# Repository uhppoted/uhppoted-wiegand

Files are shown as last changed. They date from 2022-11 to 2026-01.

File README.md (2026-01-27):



# uhppoted-wiegand

`uhppoted-wiegand` implements a RaspberryPi RP2040 based reader/emulator for a Wiegand-26 interface for:
- development, testing and debugging of access control software
- interfacing non-standard and off-brand readers and keypads to the UHPPOTE L0x access controllers

The project includes:
- _M5Stack_ Wiegand-26 emulator with:
   - isolated interface capable driving up to 32mA loads
   - can be powered from M5 bus, USB or external 12VDC supply
   - emulates both card reader and 4-bit/8-bit keypad modes
   - can operate either standalone or as an _M5Stack_ module

- breadboard prototypes
   - PIO based Wiegand-26 reader emulator which can write a Wiegand-26 card out to a controller
   - PIO based Wiegand-26 controller emulator which can read from Wiegand-26 reader and unlock a door
   - PIO based Wiegand-26 'universal' reader/writer implementation

## Status

### M5Stack

1. Wiegand emulator (Rev. 0)

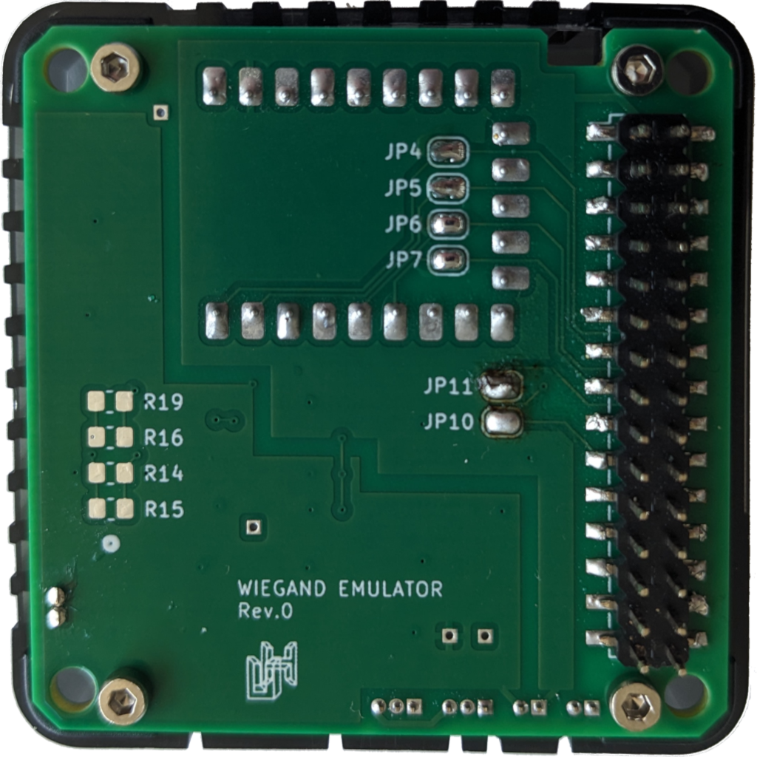
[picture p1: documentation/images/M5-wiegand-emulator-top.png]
|||

Includes:
- KiCad schematic and PCB layout
- Firmware for _Waveshare Tiny RP2040_
- Example Micropython application for _M5Stack_ _CoreS3_.

#### Errata
1. Pads for SK6812 are incorrectly numbered.
2. Anode and cathode swapped pads for D2, D3 and D4 are swapped.
3. ISO7841 doesn't allow RC filter on LED input.
4. Insufficient clearance around mounting holes.
5. DI and DO are pulled low on power-up (should default to _high_).
6. Solder mask does not include M5 connectors.
7. GPIO pins are incorrect (IO1 and IO2 instead of IO6 and IO7).

### Prototype

Breadboarded and Fritzing'ed implementations of:
- Wiegand-26 reader emulator
- Wiegand-26 controller emulator
- Wiegand-26 'universal' reader/writer

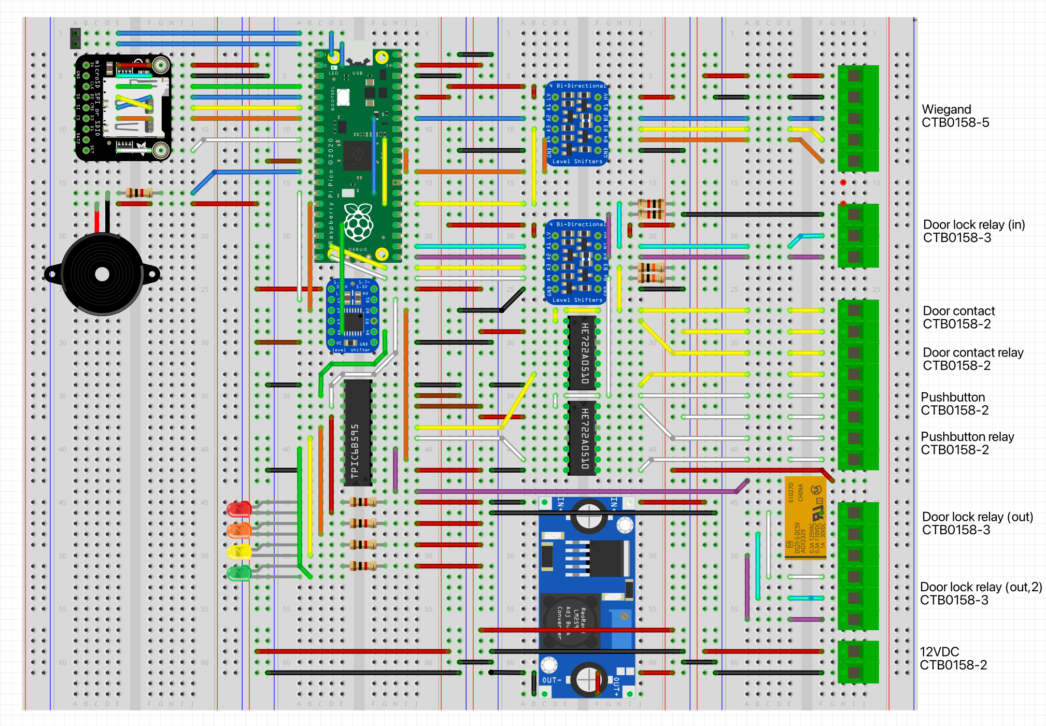
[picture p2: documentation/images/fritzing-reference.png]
 

## Release Notes

### Current Release

**[v0.9.0](https://github.com/uhppoted/uhppoted-wiegand/releases/tag/v0.9.0) - 2026-01-27**
1. Fixed GPIO card constants.
2. Added second page with keypad to demo application.

**[v0.8.11](https://github.com/uhppoted/uhppoted-wiegand/releases/tag/v0.8.11) - 2025-07-30**

1. Added M5 stack Wiegand emulator Rev.0.

## Breadboard

### Building from source

Required tools:
- [Raspberry Pi Pico C/C++ SDK](https://datasheets.raspberrypi.com/pico/raspberry-pi-pico-c-sdk.pdf)
- Compatible C/C++ compiler
- _make_
- [PicoProbe](https://github.com/raspberrypi/picoprobe) (optional but recommended)
- [OpenOCD](https://github.com/raspberrypi/openocd.git) (optional but recommended)
- [PicoTool](https://github.com/raspberrypi/picotool) (optional but recommended)

To build using the included _Makefile_:
```
git clone https://github.com/uhppoted/uhppoted-wiegand.git
cd uhppoted-wiegand/breadboard/pico
make clean
make build
```

The `build` target produces both a UF2 and an ELF binary for installation on a _Raspberry Pi Pico_ using either:
- USB (using _BOOTSEL_)
- _PicoProbe_ + _OpenOCD_
- _PicoTool_

- The `make install` command installs the binary using _PicoTool_
- The `make run` command installs the binary using _PicoProbe_ and _OpenOCD_

### Usage

The provided software includes a **very** bare bones serial port command interface. Commands are (currently)
single letter mnemonics and need to be terminated by a carriage return and/or line feed.

The supported command set comprises:

| *Command* | *Mode* | *Description* |
| ---|---|---|
| TIME yyyy-mm-dd HH:mm:ss | _ALL_ | Set date/time |
| CARD nnnnnnnn | _emulator_ | Emulates card swipe |
| CODE dddddd | _emulator_ | Emulates keypad |
| | | |
| LIST ACL | _controller_ | List cards in ACL |
| CLEAR ACL | _controller_ | Deletes all cards in ACL |
| GRANT nnnnnn dddddd | _controller_ | Grant card (+ optional PIN) access rights |
| REVOKE nnnnnn | _controller_ | Revoke card access rights |
| QUERY | _controller_ | Display last card read/write |
| | | |
| MOUNT | _ALL_ | Mount SD card |
| UNMOUNT | _ALL_ | Unmount SD card |
| FORMAT | _ALL_ | Format SD card |
| | | |
| UNLOCK | _controller_ | Unlocks door for 5 seconds |
| | | |
| OPEN | _emulator_ | Emulates door open contact |
| CLOSE | _emulator_ | Emulates door close contact |
| PRESS | _emulator_ | Emulates pushbutton press |
| RELEASE | _emulator_ | Emulates pushbutton release |
| | | |
| BLINK | _ALL_ | Blinks reader LED 5 times |
| CLS | _ALL_ | Reinitialises terminal |
| REBOOT | _ALL_ | Reboot |
| ? | _ALL_ | Display list of commands |

### Operating Modes

The codebase currently supports two operating modes:
- emulator
- controller

In _emulator_ mode the implementation writes a Wiegand-26 card code (or keypad PIN code) to an external Wiegand-26 interface
(e.g. a UHPPOTE controller). It also:
- emulates a door open/closed sensor
- emulates a door pushbutton
- detects the door locked/unlocked state

In _controller_ mode the implementation reads a Wiegand-26 card code (or keypad PIN code) from an external Wiegand-26 reader/keypad. It also:
- detects a door open/closed sensor state change
- detects a door pushbutton state change
- emulates a door lock/unlock
- implements card permissions and keypad passcodes

The operating mode is set by the combination of the code and the JUMPER_READ and JUMPER_WRITE inputs (set in _hwconfig.c_, 
GPIO7 and GPIO8 by default):
- the _controller_ binaries expect the JUMPER_READ input to be pulled LOW
- the _emulator_ binaries expected the JUMPER_WRITE input to be pulled LOW
- the _universal_ binaries start in _reader_ mode if the JUMPER_READ input is pulled LOW, or in _writer_ mode if the 
  JUMPER_WRITE is pulled LOW
- if both JUMPER_READ and JUMPER_WRITE are pulled LOW the operating mode is UNKNOWN.

### Keypad emulation

The code supports two keypad modes:
- 4-bit burst mode
- 8-bit burst mode

In 4 bit burst mode, each keypress is sent as 4 bit code followed by a 28-bit 'space', with keypad digits encoded as follows:

| Digit | 0 | 1 | 2 | 3 | 4 | 5 | 6 | 7 | 8 | 9 | * | # |
|---|---|---|---|---|---|---|---|---|---|---|---|---|
| Code  | 0000 | 0001 | 0010 | 0011 | 0100 | 0101 | 0110 | 0111 | 1000 | 1001 | 1010 | 1011 |

In 8 bit burst mode, each keypress is sent as 8 bit code followed by a 24-bit 'space', with keypad digits encoded as follows:

| Digit | 0 | 1 | 2 | 3 | 4 | 5 | 6 | 7 | 8 | 9 | * | # |
|---|---|---|---|---|---|---|---|---|---|---|---|---|
| Code  | 11110000 | 11100001 | 11010010 | 11000011 | 10110100 | 10100101 | 10010110 | 10000111 | 01111000 | 01101001 | 01011010 | 01001011 |

- In _emulator_ operating mode, the keypad mode is set by the `KEYPAD` build constant ('4-bit' or '8-bit')
- In _controller_ operating mode the keypad reader can detect and read both keypad encodings. A keycode is terminated by either a
  '#' or a 12.5 second timeout.

### Supervisor passcodes

The supervisor passcodes are _controller_ operating mode override codes that unconditionally unlocks the door.

The _controller_ operating mode supports up to four user-defined passcodes which can be set (or cleared) using the 
_PASSCODES_ command in the CLI. The passcodes may be up to 6 digits in length.

### Master passcode

In addition to the supervisor passcodes, the _controller_ operating mode provides for a MASTER override code that
unconditionally unlocks the door. The _MASTER_ override code is set at build time via the `MASTER_PASSCODE` build constant.

### Build constants

The _build constants_ in the _Makefiles_ define the initial operational settings:

| *Constant* | *Description* |
|---|---|
| `FACILITY_CODE` | The default facility code for _emulator_ mode, used if the _CARD_ command card number is 5 digits or less |
| `SYSDATE` | Initial system date |
| `SYSTIME` | Initial system time |
| `MASTER_PASSCODE` | Default master access override code |
| `KEYPAD` | Keypad mode ('4-bit' or '8-bit') |
| `SSID` | WiFi SSID |
| `PASSWORD` | WiFi password |
| `TCPD_CLI_PORT` | TCP port for the Telnet CLI |
| `TCPD_LOG_PORT` | TCP port for the network logger |
| `TCPD_SERVER_IDLE` | Idle time (seconds) after which the TCP server closes all connections and restarts |
| `TCPD_CLIENT_IDLE` | Idle time (seconds) after which a Telnet CLI client connection is closed |
| `TCPD_POLL_INTERVAL` | Internal TCP handler poll interval (ms) |
## License

Hardware is licensed under the CERN-OHL-S-2.0-S license, software is licensed under the MIT license.

## References and Related Projects

1. [Getting started with the Raspberry Pi Pico](https://datasheets.raspberrypi.com/pico/getting-started-with-pico.pdf)

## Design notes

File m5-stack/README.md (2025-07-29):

# M5Stack Wiegand Emulator

RP2040 _M5Stack_ module to emulate a Wiegand reader:

- Emulates a single Wiegand-26 card reader/keypad with an LED. 
- Implements the M5Stack serial interface.
- Intended for use with an M5 _base_ module but can optionally be powered via the external connector
  for standalone use.

## Raison d'être

Mostly to avoid having to dig out a breadboard and figure how it worked all over again every time I needed
to test a Wiegand interface.

But also useful for:
- automated testing
- testing and implementation of protocol variants

## Notes

1. The emulator uses a line driver to interface to the external controller i.e. it is not an open-collector
   and cannot be "parallelised" (as in e.g. [Will this circuit for two Wiegand card readers allow them to talk to one control board?](https://electronics.stackexchange.com/questions/535159/will-this-circuit-for-two-wiegand-card-readers-allow-them-to-talk-to-one-control). Which TBH is kindof a weird thing to do but ..).

## Status

**IN DEVELOPMENT**

## Design Notes

### Rev.0

### Notes
1. The RP2040 is **way** overkill for this application but makes for a nice development setup.
2. It's more logicial to have the ISO784x on the other side of the RP2040 but for now it allows for powering via
   USB during development.
3. Measured current draw: 55mA

#### Errata
1. Pads for SK6812 are incorrectly numbered.
2. Pads for D2, D3 and D4 are incorrect (anode and cathode swapped).
3. ISO7841 doesn't allow RC filter on LED input.
4. Insufficient clearance around mounting holes.
5. DI and DO are pulled low on power-up (should default to _high_).
6. Solder mask does not include M5 connectors.
7. GPIO pins are incorrect (IO1 and IO2 instead of IO6 and IO7).

## References

1. [M5Stack](https://m5stack.com)
2. [WaveShare RP2040-Tiny](https://www.waveshare.com/wiki/RP2040-Tiny)
3. [M5 Core Schematic(20171206)](https://m5stack.oss-cn-shenzhen.aliyuncs.com/resource/docs/schematic/Core/M5-Core-Schematic(20171206).pdf)

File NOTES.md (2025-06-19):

# NOTES

1. Use Pi Zero footprint and Red Robotics adapter
   - https://www.tomshardware.com/reviews/red-robotics-pico-2-pi-review-use-hats-with-raspberry-pi-pico
   
# R&D
1. https://www.tomshardware.com/reviews/red-robotics-pico-2-pi-review-use-hats-with-raspberry-pi-pico

2. https://hackaday.com/2022/10/23/design-your-own-chip-with-tinytapeout
3. (?) laptop Wiegand reader/writer
   - https://hackaday.com/2022/10/27/m-2-for-hackers-expand-your-laptop/

4. Relays - JQC-3FF
   - https://www.futurlec.com/Relays/JQC-3FF-24.shtml 
   - https://uk.rs-online.com/web/p/signal-relays/6839851

5. Connectors
    - https://www.wago.com/us/pcb-interconnect/pcb-terminal-block/p/2601-1106

6. Level shifters
   - https://raspberrypi.stackexchange.com/questions/100156/how-to-read-wiegand-serial-data-rx-tx
   - CD4050
   - Needs to be bidirectional though
   - BSS1338 or 2N7002 https://hackaday.com/2023/05/02/fet-fun-endeavors-together/
   - https://hackaday.com/2016/12/05/taking-it-to-another-level-making-3-3v-and-5v-logic-communicate-with-level-shifters/

7. Relay driver
   - https://kevinboone.me/pi-button-pipe.html
   - https://kevinboone.me/pi_relay.html

8. SD card
   - https://www.digikey.com/en/maker/projects/raspberry-pi-pico-rp2040-sd-card-example-with-micropython-and-cc/e472c7f578734bfd96d437e68e670050
   - http://elm-chan.org/fsw/ff/00index_e.html
   - https://apple.stackexchange.com/questions/415891/how-do-i-use-macos-terminal-or-other-app-to-format-an-mbr-fat32-sd-card-as-a-0x0
   - https://allthingsembedded.com/2018/12/29/adding-gpt-support-to-fatfs

9. PicoW + LWIP
   - https://github.com/raspberrypi/pico-sdk/issues/1079
   - https://github.com/raspberrypi/pico-sdk/issues/980
   - https://github.com/georgerobotics/cyw43-driver/issues/33

## Other

1.  https://electronics.stackexchange.com/questions/422329/cheap-12v-to-5v-dc-dc-converter-for-pcb
2.  https://www.ti.com/lit/ds/symlink/lm2596.pdf
3.  https://github.com/esprfid/esp-rfid
4.  https://www.tindie.com/products/nardev/esp-rfid-relay-board-12v-for-esp8266-board/
5.  https://github.com/rfidtool/ESP-RFID-Tool
6.  https://github.com/jvondrus/Wiegand26
7.  https://github.com/SterlingPeet/Wiegand
8.  https://www.monkeyboard.org/tutorials/82-protocol/24-wiegand-converter
9.  https://forum.arduino.cc/t/wiegand-interface/19830/3
20. https://2.bp.blogspot.com/-4SggMoZkTW8/UNhpZZauP6I/AAAAAAAABR4/IZM5tjfpcT4/s1600/screenshot.606.jpg
21. http://uggettif.blogspot.com/2014/01/access-control-with-arduino-mega.html
22. https://github.com/ugge75/Wiegand-Protocol-Library-for-Arduino-MEGA-2560
23. https://www.getkisi.com/guides/osdp
24. https://hackaday.io/project/188560-what-is-poe-my-tough-poe-development-process
25. https://www.microchip.com/en-us/product/RN171
26. https://docs.rs/embedded-tls/latest/embedded_tls/index.html
27. https://imihajlov.tk/blog/posts/eth-to-spi/q
27. https://play.google.com/store/apps/details?id=nightradio.phonopaper&gl=US
30.  https://forum.arduino.cc/t/wiegand-reader-led-xpr/649694

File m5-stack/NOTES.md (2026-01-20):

# Notes

## 125kHz RFID Reader

1. https://www.snapeda.com/parts/RDM6300/ITEAD/datasheet
2. https://hackaday.io/project/186607-125khz-tag-reader-and-contactless-lock
3. https://github.com/josevcm/nfc-laboratory
4. https://github.com/ArjanteMarvelde/uSDR-pico
5. https://hackaday.com/2024/06/05/the-pi-pico-an-sdr-receiver-front-end
6. https://www.rtl-sdr.com/pi-pico-rx-a-breadboard-software-defined-radio-based-on-the-rp2040-raspberry-pi-pico
7. https://www.elektormagazine.com/articles/raspberry-pi-pico-makes-an-msfsdr
8. https://www.cnx-software.com/2021/03/11/picosdr-a-raspberry-pi-pico-powered-sdr-based-on-gnu-radio
9. https://github.com/merbanan/rtl_433
10. https://github.com/merbanan/rtl_433/discussions/2966
11. https://www.reddit.com/r/RTLSDR/comments/1cxalli/what_antenna_for_low_frequency_125khz
12. https://electronics.stackexchange.com/questions/490243/how-to-transmit-a-125khz-signal
13. https://www.rtl-sdr.com/pi-pico-rx-a-breadboard-software-defined-radio-based-on-the-rp2040-raspberry-pi-pico
14. https://101-things.readthedocs.io/en/latest/breadboard_radio.html
15. https://blog.porucha.net/2024/pico-sdr
16. https://en.wikipedia.org/wiki/Singulation
17. https://electronics.stackexchange.com/questions/9255/rfid-antenna-array
18. https://www.microchip.com/en-us/application-notes/an710
19. https://electronics.stackexchange.com/questions/27357/diy-130khz-rfid-antenna-design-for-reading-tags-in-large-area
20. https://electronics.stackexchange.com/questions/414681/how-to-design-125khz-antenna-for-1-meter-rfid-reader
21. https://electronics.stackexchange.com/questions/490243/how-to-transmit-a-125khz-signal

## R&D
1. [Lean](https://kuruczgy.com/blog/2024/07/31/lean-esp32)

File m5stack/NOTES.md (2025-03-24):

# Notes

1. https://electronics.stackexchange.com/questions/640192/drive-long-cable-directly-with-opto-isolator-6n137-open-drain-op
2. https://electronics.stackexchange.com/questions/340184/using-differential-line-drivers-for-digital-signals
3. https://www.vishay.com/docs/80151/opticalisolatorrs232.pdf
4. https://www.ti.com/document-viewer/iso7742ta-q1/datasheet
5. https://www.ti.com/lit/ug/tiduc29a/tiduc29a.pdf?ts=1738704493564
6. https://www.analog.com/en/resources/technical-articles/icoupler-products-with-isopower-technology.html
7. https://dubinko.info/blog/2021/09/raspberry-pi-neopixel-code-wrong
8. https://wp.josh.com/2014/05/13/ws2812-neopixels-are-not-so-finicky-once-you-get-to-know-them
9. https://electronics.stackexchange.com/questions/478204/150-ws2812b-leds-with-pi-zero-and-sn74ahct125n
10. https://www.ti.com/document-viewer/lit/html/sszt517
11. https://www.ranecommercial.com/legacy/note126.html
12. https://electronics.stackexchange.com/questions/535159/will-this-circuit-for-two-wiegand-card-readers-allow-them-to-talk-to-one-control
13. https://electronics.stackexchange.com/questions/678270/trouble-with-voltage-divider-and-wiegand-reader
14. https://www.ti.com/product/ISOW7842
15. https://www.ti.com/product/ISOW7742
16. https://www.mouser.ca/ProductDetail/Texas-Instruments/ISOW7842FDWER
17. https://www.mouser.ca/ProductDetail/Texas-Instruments/ISOW7742FDFMR
18. Si86xx + Murata
19. https://www.mouser.ca/ProductDetail/onsemi/NL27WZ125USG
20. https://www.microchip.com/en-us/product/TC4427
21. https://www.ti.com/product/SN74LVC2G17
22. https://www.ti.com/product/SN74LVC2G126-EP
23. https://www.ti.com/product/TPS629206
24. https://www.ti.com/product/TPS62173
25. https://www.ti.com/product/TPS629210
26. https://www.ametherm.com/inrush-current/ptc-thermistors-for-inrush-current-limiting
27. https://www.st.com/resource/en/application_note/an6114-esd-protection-tvs-versus-mov-efficiency-comparison-stmicroelectronics.pdf
28. https://www.analog.com/en/resources/analog-dialogue/raqs/raq-issue-187.html
29. https://www.reddit.com/r/PrintedCircuitBoard/comments/16oiaoh/review_request_first_attempt_at/?rdt=39790
30. https://www.digikey.ca/en/articles/protecting-inputs-in-digital-electronics
31. https://electronics.stackexchange.com/questions/680928/unidirectional-or-bi-directional-tvs-diodes-which-one-to-use
32. https://electronics.stackexchange.com/questions/742062/robust-communication-between-%c2%b5p-board-and-i-o-expander-over-3-5-meters

## Isolation
1. https://medium.com/@jaydesai36/wiegand-interface-517a24107ede
2. https://www.galaxysys.com/sghelp/Content/C1_QRGs/Galaxy%20Reader%20Wiring%20QRG.htm
3. https://resources.wolframcloud.com/FormulaRepository/resources/Cable-Capacitance

1. Options:
   - ~~6N136 + Murata: $2.13 x 4 = $8.52 + 5.26~~
   - ISOW7842DWER: $14.47
   - ISOW7742FDFMR: $15.07
   - Si86xx + Murata: $5.12 + $5.26

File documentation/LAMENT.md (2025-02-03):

# Fritzing's Lament_

_\<sigh\> ... : 

_How many times must a man shuffle his
Breadboard layout again?
And how many wires must be trim'd and cut
Before no connection is unsound?
Oh, how many times will the LEDs be
Completely the wrong way around?
The answer, my friend
Is blowing in the wind...
The answer is blowin' in the wind!_

_Oh, how many years can a bug lurk and hide
Before it comes to the fore?
And how many years can some people exist
Happily ignorant of circuitry 
Oh, how many times must a man type ===
Before val is really truthy?
The answer, my friend
Is blowing in the wind...
The answer is blowin' in the wind!_

_And how many times can a man hook up
VSS straight to the GND?
And recalculate the series resistance
So that the relays don't fry?
Oh, how many times must a man palm his face
And ask "Oh god, f&@*&%@ why???"
The answer, my friend, is blowin' in the wind,
The answer is blowin' in the wind._

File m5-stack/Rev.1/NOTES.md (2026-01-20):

# NOTES (Rev. 1)

- https://www.vinthewrench.com/p/raspberry-pi-internet-of-things-part-2a8

1.  Use 2mmm or 2.54mm jumpers (and push through when soldering so that jumper is flush)
2.  Maybe use JST-SH connector (through hole?)
     - 1.0mm pitch JST SH connectors
     - 1.25mm pitch Molex MicroBlade
     - https://www.pcboard.ca/jst-sh-5-pin-cable
     - (?) use GROVE (standard for M5)
3.  SK6812 pad numbering incorrect
4.  Remove C1 - ISOW7841 requires fast inputs
   - either leave off altogether
   - add Schmitt trigger
5. IO6 and IO7 are assigned to GPIO2 and GPIO1
6.  Increase R8 - Vdd*R8/(R2+R13+R8) is only 4.1V
7.  ISOW784xF series has 1.5M pulldowns on inputs (pullups without F-suffix).
8.  ISOW784x datasheet recommends 0.1uF in parallel with 22uF decoupling on power pins.
   - also: see layout guidelines
   - also: https://e2e.ti.com/support/isolation-group/isolation/f/isolation-forum/836457/isow7841-isow7841-breaks-down/3107471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
   - also: https://e2e.ti.com/support/isolation-group/isolation/f/isolation-forum/846942/isow7841-isow7841-breaks-down

9.  Replace resistor network with discrete resistors (many unused/easier to solder)
10.  [ADuM320N](https://www.mouser.ca/datasheet/2/609/adum320n_321n-3420518.pdf) instead of ISOW7843
11. LED light pipes
     - https://electronics.stackexchange.com/questions/408310/attaching-a-3-mm-fiber-optic-cable-to-a-ws2812-led
     - https://www.mouser.ca/c/optoelectronics/led-indication/led-light-pipes/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
     - (?) right angle LED
     - https://www.aliexpress.com/item/1005004538582988.html
     - https://blog.adafruit.com/2023/07/06/smd5050-led-mount-light-pipe-3dthursday-3dprinting
     - https://electronics.stackexchange.com/questions/408310/attaching-a-3-mm-fiber-optic-cable-to-a-ws2812-led

12. Relocate R9 closer to U3 and swap pins.
13. Make JP4-7 normally closed so they just have to be cut if necessary (i.e. no soldering iron required).
14. Larger holes for test points.
15. Longer jumpers (or push pins through header before soldering)
16. MSP4.0A footprint is incorrect (pins are swapped)
17. Move resistor network so that RP2040 can be optionally mounted directly on board (castellated)
18. Replace WS2812B with APA102-S/SK9822/NS107S (SPI) - and 2020 package (5050 is **huge**)
    - [SK6812-SIDE](https://www.adafruit.com/product/4691)
    - txb0108
    - SN74LV1T125
    - 74LVC3G34
    - 74AHCT1G125
    - SN74LVC1T45
    - https://www.eevblog.com/forum/beginners/translate-3v-spi-to-5v-spi
    - https://protosupplies.com/product/hi-speed-spi-logic-level-converter-module
    - https://electronics.stackexchange.com/questions/18186/cheapest-way-to-translate-5v-spi-signal-to-3v-spi
    - https://www.adafruit.com/product/757
    - https://electronics.stackexchange.com/questions/378574/common-cathode-rgb-led-from-3-3v
    - https://www.lumissil.com/assets/pdf/core/IS31FL3194_DS.pdf
    - https://os.mbed.com/users/4180_1/notebook/rgb-leds
    - https://electronics.stackexchange.com/questions/48522/what-resistor-to-use-with-this-rgb-led
    - https://electronics.stackexchange.com/questions/373148/resistor-requirement-for-3-3-v-supply
    - https://electronics.stackexchange.com/questions/756253/ws2811-strip-kinda-works-with-diode-level-shifter-but-not-mosfet
    - https://electronics.stackexchange.com/questions/756103/is-it-ok-to-place-components-inside-the-pcb

19. Fix weirdly crossed signal lines between ISOW and line buffer
20. Relook at ESD/protection diodes
    - https://hackaday.com/2025/06/19/hacker-tactic-esd-diodes

21. Rotate connector side to match protoboard convention.
22. Additional clearance around mounting holes
23. Tie DI and DO high.
24. Include M5 connectors in solder mask.
25. Make **every** component hand solderable (looking at you D1 and U6 :-()
26. Buzzer IO
27. SMT headers
   - https://electronics.stackexchange.com/questions/415542/are-these-tiny-vertical-dual-row-pcb-mounted-connector-pins-standard/719876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
28. PCB notch for CoreS3 power switch
29. Slot in enclosure for USB cable
30. WS2812 level translation
    - https://electronics.stackexchange.com/questions/756253/ws2811-strip-kinda-works-with-diode-level-shifter-but-not-mosfet
31. Maybe put ESD diodes on back?
    - https://hackaday.com/2025/12/09/pcb-design-review-tinysparrow-a-module-for-can-hacking-v2/

- https://hackaday.com/2025/09/09/freecad-foray-from-brick-to-shell/
- (?) https://www.ti.com/product/MSPM0C1104
- (?) Add HWPR as optional power

## Other
- https://www.digikey.com/en/products/detail/qt-brightek-qtb/QBLP617-IW/4814678
- https://www.sparkfun.com/sparkfun-rgb-addressable-cbi-led-5mm-right-angle.html
- https://www.sparkfun.com/sparkfun-cbi-light-pipe-for-smd-leds-5mm-right-angle.html
- https://www.sparkfun.com/led-rgb-addressable-pth-5mm-clear-5-pack.html
- https://www.mouser.ca/c/?marcom=109216310
- https://www.digikey.ca/en/products/filter/led-indication-discrete/through-hole-right-angle/105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
- https://www.raspberrypi.com/news/raspberry-pi-poe-injector-on-sale-now-at-25/

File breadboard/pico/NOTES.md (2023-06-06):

# NOTES

1. PIO interrupts
   - https://forums.raspberrypi.com/viewtopic.php?t=312516
   - https://forums.raspberrypi.com/viewtopic.php?t=326979

2. USB + WiFi
   - https://forums.raspberrypi.com/viewtopic.php?t=340270

3. CYW43 sysled - invoking from a repeating timer callback seems to cause a lockup
   if invoked at intervals less than 500ms.

4. 10058339
   0 0110 0100 1110 0100 0001 1111 1
     6    4    e    4    1    f
     start parity: 6+0 ones (e)
     end parity:   6+1 ones (o)

   00c9c83f
   xxxx xx00 1100 1001 1100 1000 0011 1111
   00 1100 1001 1100 1000 0011 1111
   0 0110 0100 1110 0100 0001 1111 1

   Even parity:
   0 0110 0100 1110 0100 0001 1111 1
   1 1111 1111 1111 0000 0000 0000 0
   0000 0011 1111 1111 1110 0000 0000 0000
   0    3    f    f    e    0    0    0

   odd parity:
   0 0110 0100 1110 0100 0001 1111 1
   0 0000 0000 0000 1111 1111 1111 1
   0000 0000 0000 0000 0001 1111 1111 1111
   0    0    0    0    1    f    f    f

5. https://www.raspberrypi.com/news/how-to-add-ethernet-to-raspberry-pi-pico/

### Debugging reader glitch
```
2023-01-06 13:39:50  DEBUG: 21 264255
0x0004083F

0000 0000 0100 0000 1000 0011 1111

10058399
64e41f
0110 0100 1110 0100 0001 1111
0 0110 0100 1110 0100 0001 1111 1
00 1100 1001 1100 1000 0011 1111
0000 0000 1100 1001 1100 1000 0011 1111
0    0    c     9   c    8    3     f

     0000 0000 0100 0000 1000 0011 1111
```

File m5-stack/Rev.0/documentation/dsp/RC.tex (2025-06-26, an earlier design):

\documentclass{article}
\usepackage{amsmath}

\begin{document}

To reduce a 5\,V signal to 2\,V at 500\,Hz using a first-order RC low-pass filter, we need to determine the cutoff frequency \( f_c \) such that the filter attenuates the signal appropriately.

For a first-order RC low-pass filter, the gain at frequency \( f \) is given by:

\[
|H(f)| = \frac{1}{\sqrt{1 + \left( \frac{f}{f_c} \right)^2 }}
\]

We require:

\[
|H(500\,\text{Hz})| = \frac{2}{5} = 0.4
\]

Solving for \( f_c \):

\[
0.4 = \frac{1}{\sqrt{1 + \left( \frac{500}{f_c} \right)^2 }}
\]

\[
\sqrt{1 + \left( \frac{500}{f_c} \right)^2 } = \frac{1}{0.4} = 2.5
\]

\[
1 + \left( \frac{500}{f_c} \right)^2 = 6.25
\]

\[
\left( \frac{500}{f_c} \right)^2 = 5.25
\]

\[
\frac{500}{f_c} = \sqrt{5.25} \approx 2.291
\]

\[
f_c = \frac{500}{2.291} \approx \boxed{218.3\,\text{Hz}}
\]

Therefore, the filter should be designed with a cutoff frequency of approximately 218\,Hz to achieve the desired attenuation at 500\,Hz.

\end{document}

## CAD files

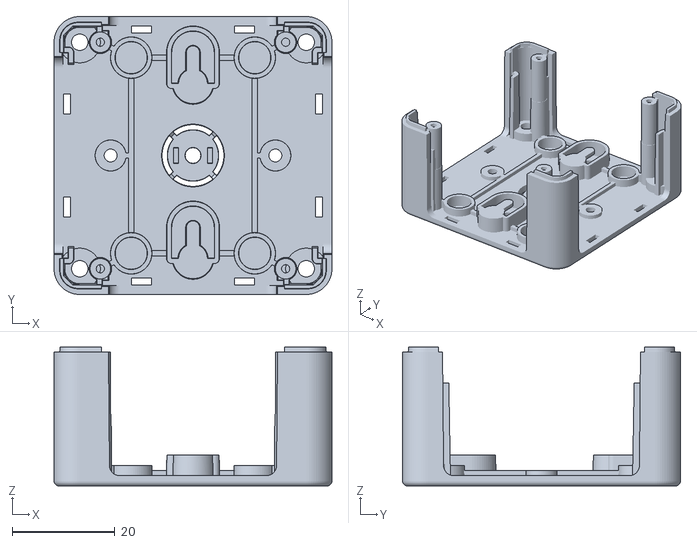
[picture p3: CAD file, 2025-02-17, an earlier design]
m5-stack/Rev.0/documentation/m5stack/Base26_main.stl
54.0 x 54.0 x 27.0

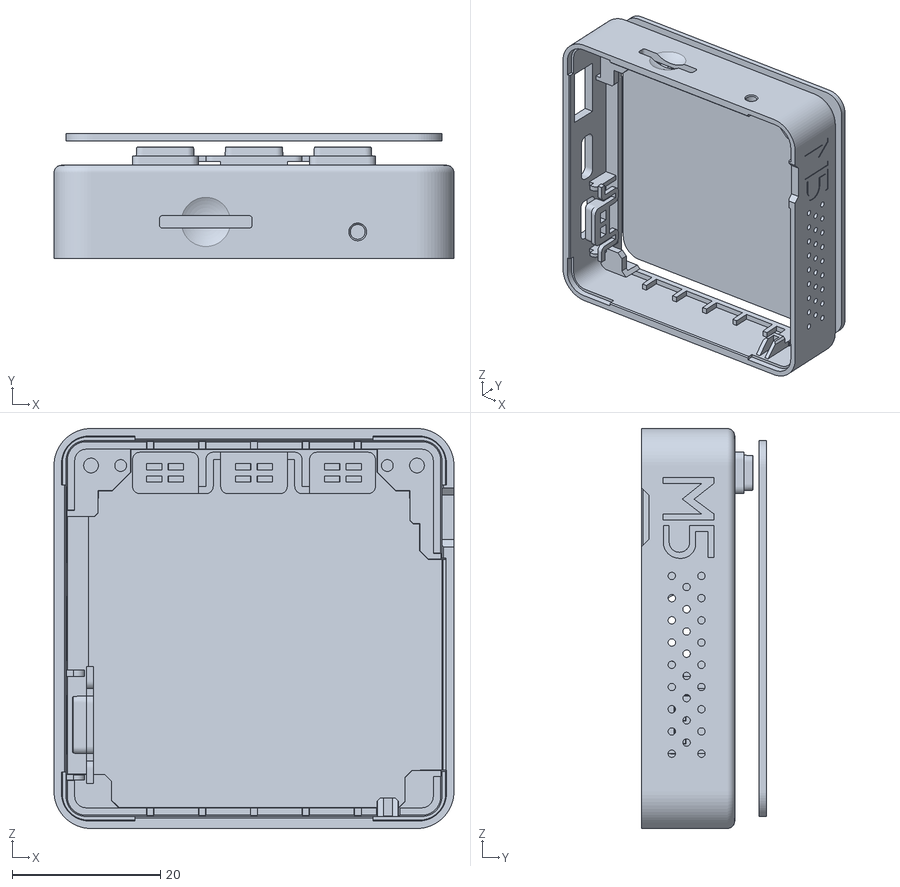
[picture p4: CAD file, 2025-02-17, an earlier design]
m5-stack/Rev.0/documentation/m5stack/core.stl
54.0 x 16.9 x 54.0

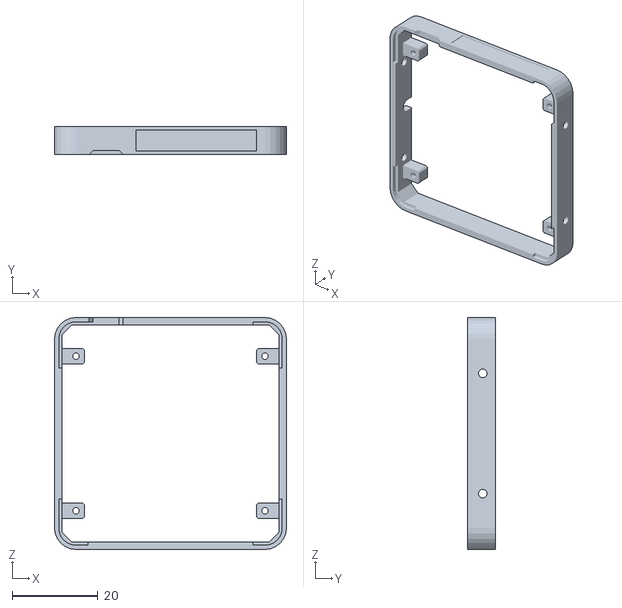
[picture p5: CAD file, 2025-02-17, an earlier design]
m5-stack/Rev.0/documentation/m5stack/PROTO.stl
54.0 x 6.60 x 54.0

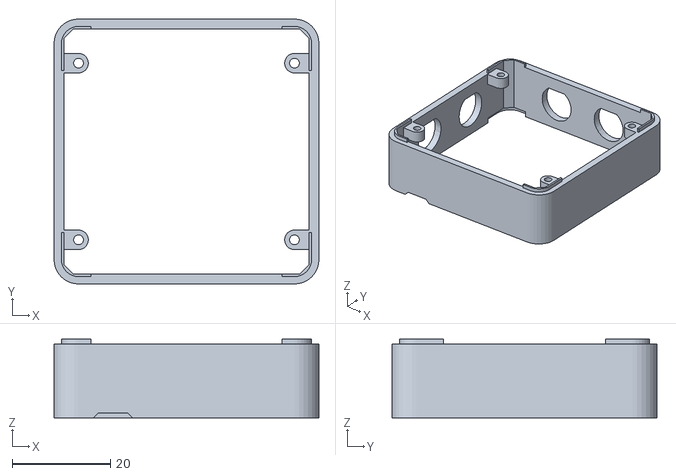
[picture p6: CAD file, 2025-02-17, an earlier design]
m5-stack/Rev.0/documentation/m5stack/Oscilloscope_Case.stl
54.0 x 54.0 x 16.0

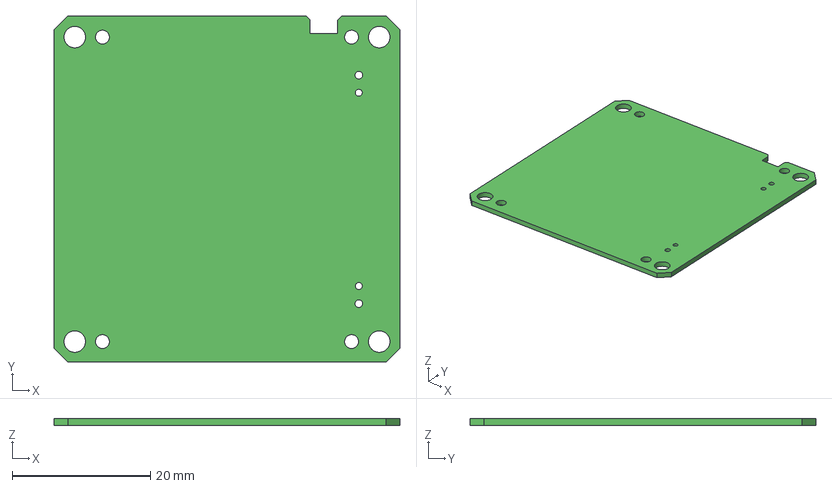
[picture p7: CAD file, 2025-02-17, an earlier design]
m5-stack/Rev.0/documentation/m5stack/Module-Type-A.step
50.0 x 50.0 x 1.00 mm

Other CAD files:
m5-stack/Rev.0/documentation/m5stack/Module-Type-A.dxf

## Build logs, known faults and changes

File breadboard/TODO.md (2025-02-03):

# TODO

- (?) Make -Wimplicit-function-declaration an error

- [ ] PicoW+TCP/IP
      - [ ] Figure out SD card detect interrupt conflict
            - (?) Use GPIO poll
            - https://github.com/georgerobotics/cyw43-driver/issues/33
            - https://github.com/raspberrypi/pico-sdk/issues/1068
            - https://forums.raspberrypi.com/viewtopic.php?t=348664
            - https://github.com/sekigon-gonnoc/Pico-PIO-USB/issues/76

   - [ ] Buzzer
   - (?) CLI auth
         - HOTP
   - (?) Replace CLI with API
   - [ ] tweetnacl/TLS
         - [ ] TCP/IP
         - (?) ACL
         - (?) Auth

   - (?) DTMF

## Schematic
- RD/WR jumpers
- Mode jumpers
- Buzzer
  - through-hole so that it can be routed to enclosue
- LEDs 
  - through-hole so that they can be routed to enclosue
- Reset button
- SD card
- (?) Long line drivers
- (?) PiZero header

## Other
1. [NuttX](https://nuttx.apache.org/docs/latest/platforms/index.html)
2. [RiotOS](https://www.riot-os.org)

## NOTES

1. Delta time for card read is 53ms (~2ms/bit)
2. PIO clock 
   - 125MHz   -> 8ns per instruction
   - nop [32] -> 256ns  => 0.256us
   - 32x loop -> 8192ns => 8.192us
   - div 64 => 0.5ms
   - configured at 152.588 (~1.25s)
   - maximum div for reliable reads is 192 (~1.6ms)

3. https://github.com/teslamotors/liblithium
4. https://www.mouser.ca/ProductDetail/Microchip-Technology-Atmel/ATECC608A-MAHDA-T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
   - https://www.sparkfun.com/products/18077
   - https://www.mikroe.com/secure-4-click
5. Lua
   - https://github.com/kevinboone/luapico
   - https://sillycross.github.io/2022/11/22/2022-11-22/

6. TPIC6B595
   - https://www.ti.com/lit/an/slpa004a/slpa004a.pdf
   - https://docs.arduino.cc/tutorials/communication/guide-to-shift-out
   - https://www.appelsiini.net/2012/driving-595-shift-registers/#spcr
   - https://e2e.ti.com/support/power-management-group/power-management/f/power-management-forum/1133532/tpic6595-relay-back-emf

7. Level shifters
   - https://www.tindie.com/products/ddebeer/12v-level-shifter-and-buffer-2x6-channel
   - https://electronics.stackexchange.com/questions/486571/12v-to-3-3-v-logic-level-shifter

8. Relay drivers
   - https://electronics.stackexchange.com/questions/585207/uln2003-relay-driver
   - https://electronics.stackexchange.com/questions/258081/uln2003-used-for-security-door-magnets
   - https://electronics.stackexchange.com/questions/357351/shift-register-that-accepts-3-3v-to-drive-several-5v-relays
   - https://electronics.stackexchange.com/questions/505318/how-to-properly-use-a-relay-module-with-jd-vcc-from-arduino-raspberry/508672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
   - https://raspberrypi.stackexchange.com/questions/118604/using-single-5v-relay-module-jqc-3ff-s-z-asking-for-help

9. USB
   - https://forums.raspberrypi.com/viewtopic.php?t=331207
   - https://github.com/raspberrypi/pico-examples/issues/19
   - https://forums.raspberrypi.com/viewtopic.php?t=333027
   - https://blog.smittytone.net/2021/10/31/how-to-send-data-to-a-raspberry-pi-pico-via-usb
   - https://blog.smittytone.net/2022/02/16/pico-usb-serial-communications-with-circuitpython
   - https://forum.micropython.org/viewtopic.php?t=11305

10. PicoW
   - https://github.com/micropython/micropython/issues/9003
   - https://stackoverflow.com/questions/74883568/oserror-errno-12-enomem-with-pi-pico-w
   - https://github.com/sekigon-gonnoc/Pico-PIO-USB/discussions/78
   - https://github.com/sekigon-gonnoc/Pico-PIO-USB/issues/76
   - https://www.nongnu.org/lwip/2_1_x/index.html
   - https://www.scaprile.com/2023/02/05/on-hardware-state-machines-how-to-write-a-simple-mac-controller-using-the-rp2040-pios
   - https://ww1.microchip.com/downloads/en/Appnotes/Atmel-42233-Using-the-lwIP-Network-Stack_AP-Note_AT04055.pdf
   - https://forums.raspberrypi.com/viewtopic.php?t=337666
   - https://forums.raspberrypi.com/viewtopic.php?t=349890
   
11. PicoW + SYSLED
   - https://smist08.wordpress.com/2022/08/26/introducing-the-raspberry-pi-pico-w/
   - https://forums.raspberrypi.com/viewtopic.php?t=348664
   - https://datasheets.raspberrypi.com/picow/connecting-to-the-internet-with-pico-w.pdf
   - https://www.raspberrypi.com/documentation/pico-sdk/networking.html#pico_cyw43_driver

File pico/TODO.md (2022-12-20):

# TODO

1.  [x] Reset bit decoder on timeout
2.  [x] Join FIFOs
3.  [x] Debounce properly
4.  [x] Signal read timeout
5.  [x] Status LEDs
6.  [x] Replace sleep with queue wait/interrupt
7.  [x] Move reader to its own file
8.  [x] Restructure folders to use src and include
9.  [x] https://stackoverflow.com/questions/109023/count-the-number-of-set-bits-in-a-32-bit-integer
10. [x] ~~Alternative implementations using two SMs and WAIT pin~~
11. [x] Move remaining card stuff to reader.c
12. [x] README
13. [x] Mode reader/emulator/unknown
14. [x] CLI
15. [ ] Emulator
        - [x] CLI WRITE command
        - [x] writer_write
        - [x] WRITE.pio
        - [x] PIO/shift-and-set
        - [x] Card readback
        - [x] Set bit delay to 1ms (x2)
        - [x] Not formatting card number correctly to actual controller
```
405419896  ... 2022-12-20 12:27:44 0          0 00 00 | 206924 1   false 3 1     10058399   2022-12-20 12:27:44 6
405419896  ... 2022-12-20 12:29:16 0          0 00 00 | 206925 1   false 4 1     1058399    2022-12-20 12:29:16 6

reader:
>> DEBUG: 13223999 00c9c83f

emulator:
>> DEBUG: 34981951 0215c83f
```

        - [ ] Ignore if not emulator mode
        - [ ] QUERY - show R/W
        - [ ] startup glitch

16. [ ] Prototype schematic
        - LEDs
        - Move all the Wiegand I/O to one side
        - Relay driver
        - Door input
        - Door relay
        - (?) Fritzing

17. [ ] Schematic
        - Relay driver
        - Door input
        - Door relay
        - LEDs
        - (?) Long line drivers
        - (?) PiZero header

## NOTES

1. Delta time for card read is 53ms (~2ms/bit)
2. PIO clock 
   - 125MHz   -> 8ns per instruction
   - nop [32] -> 256ns  => 0.256us
   - 32x loop -> 8192ns => 8.192us
   - div 64 => 0.5ms
   - configured at 152.588 (~1.25s)
   - maximum div for reliable reads is 192 (~1.6ms)

3. https://github.com/teslamotors/liblithium
4. https://www.mouser.ca/ProductDetail/Microchip-Technology-Atmel/ATECC608A-MAHDA-T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
   - https://www.sparkfun.com/products/18077
   - https://www.mikroe.com/secure-4-click
5. Lua
   - https://github.com/kevinboone/luapico
   - https://sillycross.github.io/2022/11/22/2022-11-22/

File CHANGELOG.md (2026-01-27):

# CHANGELOG

## Unreleased

## [0.9.0](https://github.com/uhppoted/uhppoted-wiegand/releases/tag/v0.9.0) - 2026-01-27

### Updated
1. Fixed GPIO card constants.
2. Added second page with keypad to demo application.

## [0.8.11](https://github.com/uhppoted/uhppoted-wiegand/releases/tag/v0.8.11) - 2025-07-30

### Added
1. M5 stack Wiegand emulator Rev.0.

## [0.8.10](https://github.com/uhppoted/uhppoted-wiegand/releases/tag/v0.8.10) - 2025-01-31

### Updated
1. Updated labels in READ.pio for RP2350 reserved words.

## [0.8.9](https://github.com/uhppoted/uhppoted-wiegand/releases/tag/v0.8.9) - 2024-09-06

1. Maintenance release for version consistency.

## [0.8.8](https://github.com/uhppoted/uhppoted-wiegand/releases/tag/v0.8.8) - 2024-03-27

1. Maintenance release for version consistency.

## [0.8.7](https://github.com/uhppoted/uhppoted-wiegand/releases/tag/v0.8.7) - 2023-12-01

### Added
1. Keypad emulation
2. Passcode access override
3. Card + optional PIN access
4. _clear-acl_ command

### Updated
1. Fixed bug in SD card _store-acl_ logic.
2. Renamed 'reference' implementation to 'universal'

## [0.8.6](https://github.com/uhppoted/uhppoted-wiegand/releases/tag/v0.8.6) - 2023-08-30

### Added
1. Uses on-board flash for ACL

### Updated
2. Fixed SD card ACL write for missing ACL file.

## [0.8.5](https://github.com/uhppoted/uhppoted-wiegand/releases/tag/v0.8.5) - 2023-06-14

### Added
1. PicoW base and USB variants
2. PicoW WiFi variants

## [0.8.4](https://github.com/uhppoted/uhppoted-wiegand/releases/tag/v0.8.4) - 2023-03-17

1. Initial release of Raspberry Pi Pico Wiegand-26 reader/emulator

## Older

| *Version* | *Description* |
| --- | --- |
| v0.8.3 | Adds AMR64 to release builds |
| v0.8.2 | Adds _uhppoted-codegen_ project to generate native UHPPOTE interface in languages other thann Go |
| v0.8.1 | Adds human readable fields to events for MQTT and REST implementations. Minor bug fixes and usability fixes |
| v0.8.0 | Initial release for _uhppoted-httpd_ and _uhppoted-tunnel_ |
| v0.7.3 | Adds [uhppoted-dll](https://github.com/uhppoted/uhppoted-dll) shared-lib to components |
| v0.7.2 | Replaces event rollover with _forever_ incrementing indices to match observed behaviour |
| v0.7.1 | Adds support for controller task list management |
| v0.7.0 | Adds support for time profiles. Includes bundled release of `uhppoted-nodejs` NodeJS module |
| v0.6.12 | Reworked concurrency and additional configuration |
| v0.6.10 | Initial release for `uhppoted-app-wild-apricot` |
| v0.6.8 | Adds handling for v6.62 firmware _listen events_ to `node-red-contrib-uhppoted` |
| v0.6.7 | Implements `record-special-events` to enable/disable door events |
| v0.6.5 | `node-red-contrib-uhppoted` module for use with NodeRED low code environment |
| v0.6.4 | `uhppoted-app-sheets` Google Sheets integration module |
| v0.6.3 | Added access control list commands to `uhppoted-mqtt` |
| v0.6.2 | Added access control list commands to `uhppoted-rest` |
| v0.6.1 | Added access control list commands to `uhppote-cli` |
| v0.6.0 | `uhppoted-app-s3` AWS S3 integration module |
| v0.5.1 | Initial release following restructuring into standalone Go *modules* and *git submodules* |
| v0.5.0 | Add MQTT endpoint for remote access to UT0311-L0x controllers |
| v0.4.2 | Reworked `GetDevice` REST API to use directed broadcast and added get-device to CLI |
| v0.4.1 | Get/set door control state functionality added to simulator, CLI and REST API |
| v0.4.0 | REST API service |
| v0.3.1 | Functional simulator with minimal command API |
| v0.2.0 | Load access control list from TSV file |
| v0.1.0 | Bare-bones but functional CLI |

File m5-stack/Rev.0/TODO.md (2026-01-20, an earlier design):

# TODO

- [x] Schematic
- [x] PCB
- [x] Design Review
- [x] CoreS3
- [x] Firmware
- [x] README 
- [x] Power
   - [x] USB
   - [x] M5
   - [x] Power module

## USB
- [x] RaspberryPi
- [ ] MacOS
- https://github.com/piersfinlayson/tinyusb-vendor-example
- https://github.com/piersfinlayson/picoboot

## [ ] Enclosure
   - https://github.com/uetchy/m5stack-module

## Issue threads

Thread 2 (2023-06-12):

Use onboard flash for ACL

uhppoted, 2023-06-12:
- https://www.makermatrix.com/blog/read-and-write-data-with-the-pi-pico-onboard-flash
- https://forums.raspberrypi.com/viewtopic.php?t=305570

twystd, 2023-08-23:
Feature complete - pending release v0.8.6

Closed 2023-08-23.

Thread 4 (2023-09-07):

Emulate keypad

uhppoted, 2023-09-07:
Emulate keypad for:
- super password/PIN
- card+PIN

### Notes:
1. https://www.farpointedata.com/downloads/qsg_and_ref/KeypadMode_REF.pdf
2. https://www.keyless.com/wp-content/uploads/2019/01/TProxInstallationManual.pdf
3. https://github.com/uhppoted/uhppoted/issues/40
4. https://nodemcu.readthedocs.io/en/release/modules/wiegand
5. https://github.com/rfidtool/ESP-RFID-Tool

twystd, 2023-10-26:
Added keypad emulation:
- 4-bit burst mode
- 8-bit burst mode
- card + PIN

Pending release v0.8.7

Closed 2023-10-26.

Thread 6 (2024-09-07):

Rework PIO programs to avoid rx/tx (RP2350 reserved)

twystd, 2024-09-07:
cf. https://github.com/raspberrypi/pico-sdk/issues/1911

twystd, 2024-09-09:
Updated _rx_ label to not confict with RP2350 reserved word. Closing as completed.

Closed 2024-09-09.

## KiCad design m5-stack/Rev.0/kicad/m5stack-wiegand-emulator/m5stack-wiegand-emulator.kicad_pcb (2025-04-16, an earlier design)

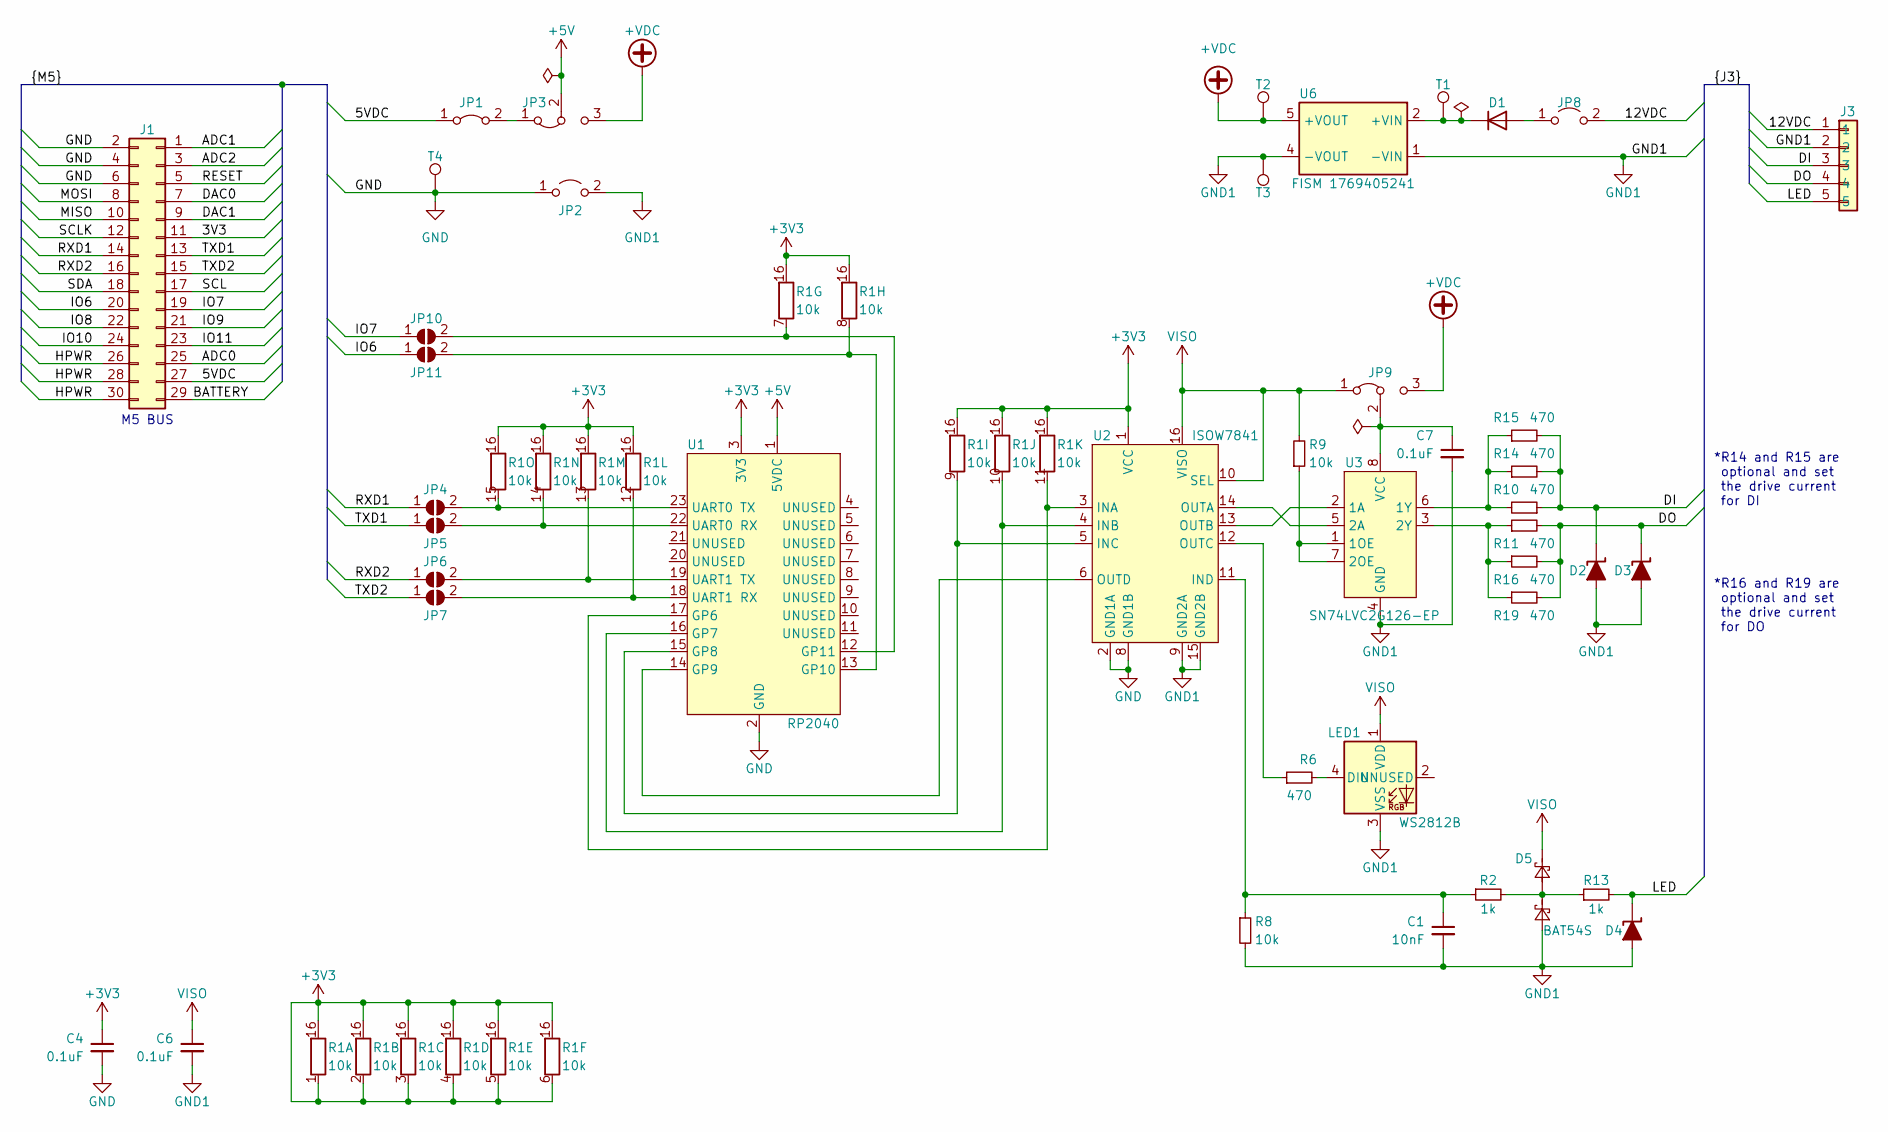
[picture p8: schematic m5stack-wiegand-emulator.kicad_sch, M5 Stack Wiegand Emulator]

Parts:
C1: 10nF; C_0805_2012Metric_Pad1.18x1.45mm_HandSolder
C4, C6, C7: 0.1uF; C_0805_2012Metric_Pad1.18x1.45mm_HandSolder
D1: GF1A; DIODE_DO-214BA
D2, D3, D4: MSP5.0A
D5: BAT54S; SOT-23
J1: 2x15 socket header; M5Stack Bus SMD connector
J3: 1x5 female; Molex 532610571
JP1, JP2: Jumper_2_Bridged; PinHeader_1x02_P1.27mm_Vertical
JP3, JP9: Jumper_3_Bridged12; PinHeader_1x03_P1.27mm_Vertical
JP4, JP5, JP6, JP7, JP10, JP11: Jumper:SolderJumper_2_Open; SolderJumper-2_P1.3mm_Open_RoundedPad1.0x1.5mm
JP8: Jumper; PinHeader_1x02_P1.27mm_Vertical
LED1: WS2812B; LED_WS2812B_PLCC4_5.0x5.0mm_P3.2mm
R1: 10k; EXB-Q16P103J
R2, R13: 1k; R_0805_2012Metric_Pad1.20x1.40mm_HandSolder
R6, R10, R11, R14, R15, R16, R19: 470; R_0805_2012Metric_Pad1.20x1.40mm_HandSolder
R8, R9: 10k; R_0805_2012Metric_Pad1.20x1.40mm_HandSolder
T1, T2, T3, T4: TestPoint; TestPoint_THTPad_1.0x1.0mm_Drill0.5mm
U1: RP2040; RP2040-TINY
U2: ISOW7841; DWE0016A
U3: SN74LVC2G126-EP; VSSOP-8_2.4x2.1mm_P0.5mm
U6: FISM 1769405241; WPME-FISM_SMT-8_1769205241

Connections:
+3V3: C4.1, R1.1 (R15.2), R1.2 (R2.2), R1.3 (R3.2), R1.4 (R4.2), R1.5 (R5.2), R1.6 (R6.2), R1.16 (R1), U1.3 (3V3), U2.1 (VCC)
+5V: JP3.2 (C), U1.1 (5VDC)
+VDC: JP3.3 (B), JP9.3 (B), T2.1, U6.5 (+VOUT)
/3V3: J1.11
/5VDC: J1.27, JP1.1 (A)
/12VDC: J3.1, JP8.2 (B)
/ADC0: J1.25
/ADC1: J1.1
/ADC2: J1.3
/BATTERY: J1.29
/DAC0: J1.7
/DAC1: J1.9
/DI: D2.1 (A1), J3.3, R10.1, R14.2, R15.2
/DO: D3.1 (A1), J3.4, R11.2, R16.2, R19.2
/HPWR: J1.26, J1.28, J1.30
/IO6: J1.20, JP11.1 (A)
/IO7: J1.19, JP10.1 (A)
/IO8: J1.22
/IO9: J1.21
/IO10: J1.24
/IO11: J1.23
/LED: D4.1 (A1), J3.5, R13.2
/MISO: J1.10
/MOSI: J1.8
/RESET: J1.5
/RXD1: J1.14, JP4.1 (A)
/RXD2: J1.16, JP6.1 (A)
/SCL: J1.17
/SCLK: J1.12
/SDA: J1.18
/TXD1: J1.13, JP5.1 (A)
/TXD2: J1.15, JP7.1 (A)
GND: C4.2, J1.2, J1.4, J1.6, JP2.1 (A), T4.1, U1.2 (GND), U2.2 (GND1A), U2.8 (GND1B)
GND1: C1.2, C6.2, C7.2, D2.2 (A2), D3.2 (A2), D4.2 (A2), D5.1 (A), J3.2, JP2.2 (B), LED1.3 (VSS), R8.2, T3.1, U2.9 (GND2A), U2.15 (GND2B), U3.4 (GND), U6.1 (-VIN), U6.4 (-VOUT)
unnamed: D1.2 (A), JP8.1 (A)
unnamed: D1.1 (K), T1.1, U6.2 (+VIN)
unnamed: D5.3 (COM), R2.2, R13.1
unnamed: JP1.2 (B), JP3.1 (A)
unnamed: JP4.2 (B), R1.15 (R15.2), U1.23 (UART0 TX)
unnamed: JP5.2 (B), R1.14 (R15.2), U1.22 (UART0 RX)
unnamed: JP6.2 (B), R1.13 (R15.2), U1.19 (UART1 TX)
unnamed: JP7.2 (B), R1.12 (R15.2), U1.18 (UART1 RX)
unnamed: C7.1, JP9.2 (C), U3.8 (VCC)
unnamed: JP10.2 (B), R1.7 (R7.2), U1.12 (GP11)
unnamed: JP11.2 (B), R1.8 (R8.2), U1.13 (GP10)
unnamed: LED1.4 (DIN), R6.2
unnamed: R1.9 (R15.2), U1.15 (GP8), U2.5 (INC)
unnamed: R1.10 (R15.2), U1.16 (GP7), U2.4 (INB)
unnamed: R1.11 (R15.2), U1.17 (GP6), U2.3 (INA)
unnamed: U1.14 (GP9), U2.6 (OUTD)
unnamed: C1.1, R2.1, R8.1, U2.11 (IND)
unnamed: U2.14 (OUTA), U3.5 (2A)
unnamed: U2.13 (OUTB), U3.2 (1A)
unnamed: R6.1, U2.12 (OUTC)
unnamed: R9.1, U3.1 (1OE), U3.7 (2OE)
unnamed: R10.2, R14.1, R15.1, U3.6 (1Y)
unnamed: R11.1, R16.1, R19.1, U3.3 (2Y)
VISO: C6.1, D5.2 (K), JP9.1 (A), LED1.1 (VDD), R9.2, U2.10 (SEL), U2.16 (VISO)

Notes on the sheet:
*R14 and R15 are optional and set the drive current for DI
*R16 and R19 are optional and set the drive current for DO
M5 BUS

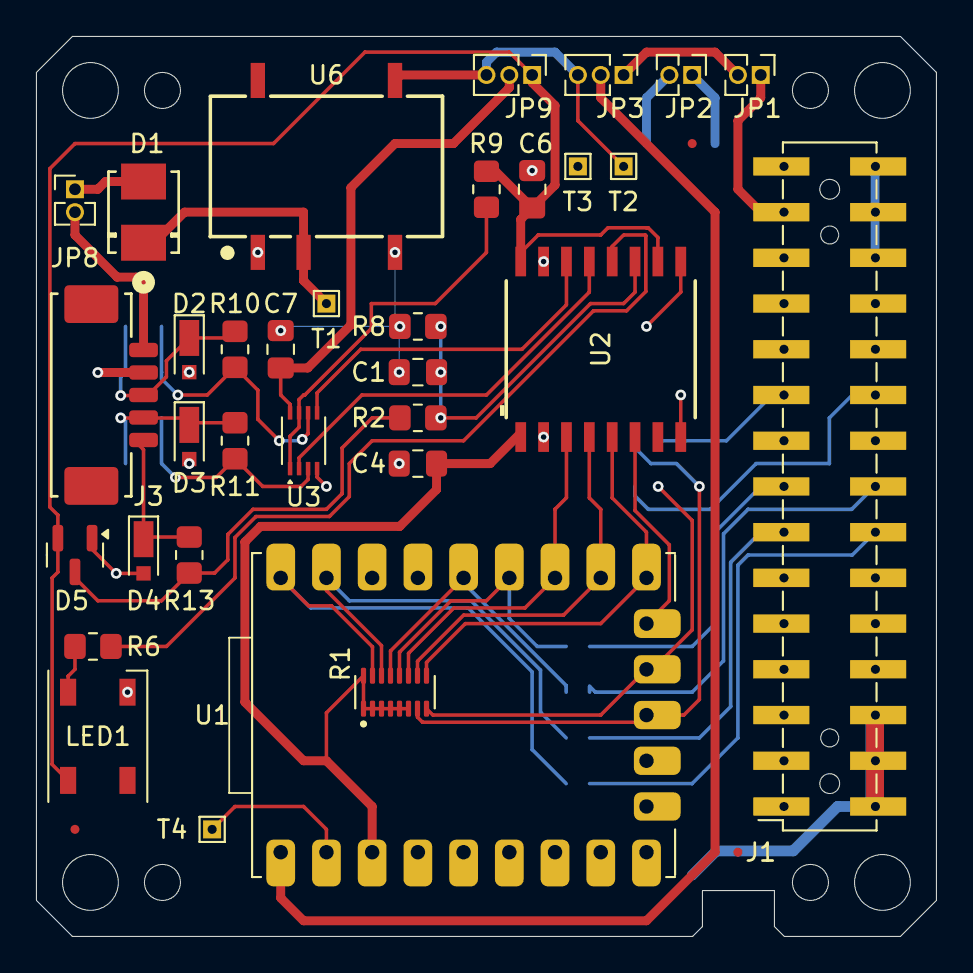
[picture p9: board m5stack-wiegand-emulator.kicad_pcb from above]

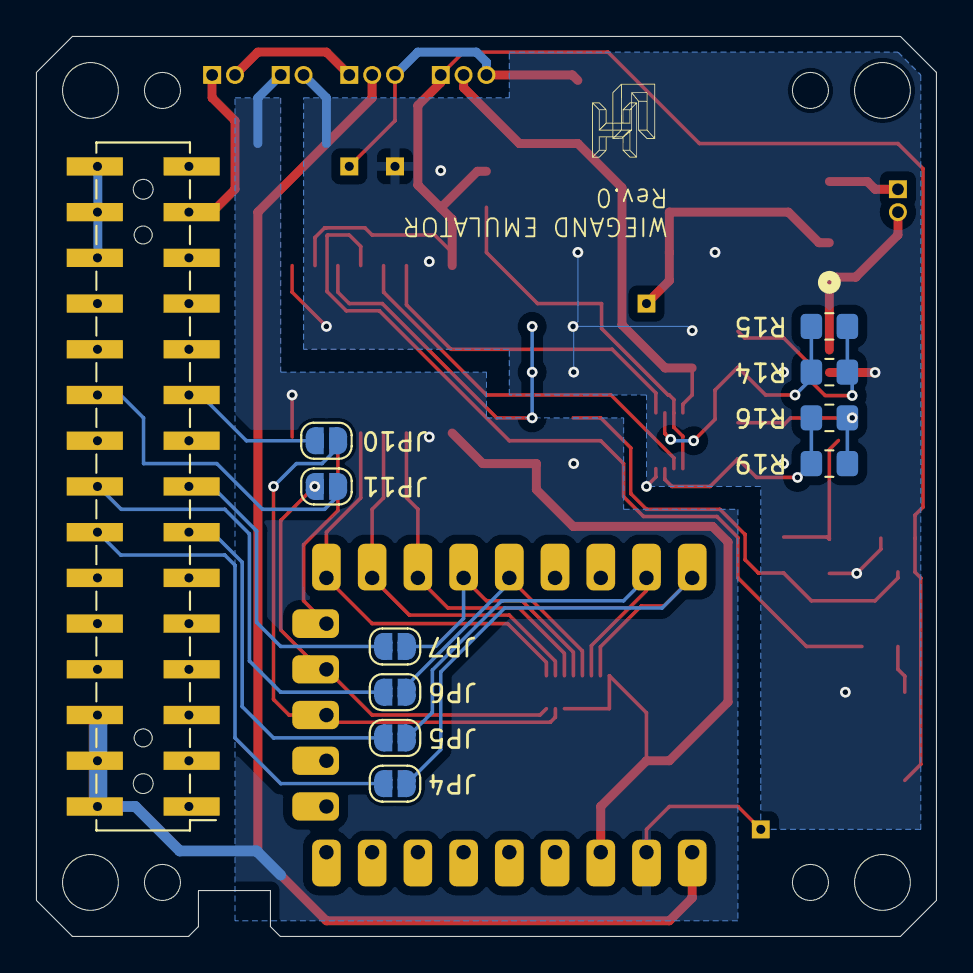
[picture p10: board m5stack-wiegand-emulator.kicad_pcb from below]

Board: 2 copper layers, 50.0 x 50.0 mm, 54 parts (10 on the bottom side), 41 nets.

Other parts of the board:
F1, F2, F3: Fiducial_0.5mm_Mask1mm
M1, M2, M3, M4: M5Stack 3.1mm mounting hole
M5, M6, M7, M7#2: M5Stack 2mm mounting hole

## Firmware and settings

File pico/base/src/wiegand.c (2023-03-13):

#include <stdio.h>
#include <stdlib.h>
#include <string.h>

#include "hardware/gpio.h"
#include "hardware/rtc.h"
#include "hardware/watchdog.h"

#include "pico/binary_info.h"
#include "pico/multicore.h"
#include "pico/stdlib.h"
#include "pico/util/datetime.h"

#include "../include/TPIC6B595.h"
#include "../include/acl.h"
#include "../include/buzzer.h"
#include "../include/common.h"
#include "../include/led.h"
#include "../include/read.h"
#include "../include/relays.h"
#include "../include/sdcard.h"
#include "../include/sys.h"
#include "../include/uart.h"
#include "../include/wiegand.h"
#include "../include/write.h"

#define VERSION "v0.0.0"

#define UART0 uart0
#define UART1 uart1
#define BAUD_RATE 115200
#define DATA_BITS 8
#define STOP_BITS 1
#define PARITY UART_PARITY_NONE

// GPIO
const uint GPIO_25 = 25;
const uint ONBOARD_LED = GPIO_25; // Pico LED

const uint32_t MSG = 0xf0000000;
const uint32_t MSG_WATCHDOG = 0x00000000;
const uint32_t MSG_SYSCHECK = 0x10000000;
const uint32_t MSG_RX = 0x20000000;
const uint32_t MSG_TX = 0x30000000;
const uint32_t MSG_CARD_READ = 0x40000000;
const uint32_t MSG_LED = 0x50000000;
const uint32_t MSG_RELAY = 0x60000000;
const uint32_t MSG_DOOR = 0x70000000;
const uint32_t MSG_PUSHBUTTON = 0x80000000;
const uint32_t MSG_RXI = 0xd0000000;
const uint32_t MSG_SYSINIT = 0xe0000000;
const uint32_t MSG_DEBUG = 0xf0000000;

// FUNCTION PROTOTYPES

void setup_gpio(void);
void setup_uart(void);
void sysinit();

int64_t startup(alarm_id_t, void *);
int64_t timeout(alarm_id_t, void *);
bool watchdog(repeating_timer_t *);
bool syscheck(repeating_timer_t *);

// GLOBALS
enum MODE mode = UNKNOWN;
queue_t queue;

card last_card = {
    .facility_code = 0,
    .card_number = 0,
    .ok = false,
};

// UART
void on_uart0_rx() {
    char buffer[32];
    int ix = 0;

    while (uart_is_readable(UART0) && ix < sizeof(buffer)) {
        buffer[ix++] = uart_getc(UART0);
    }

    if (ix > 0) {
        char *b;

        if ((b = calloc(ix + 1, 1)) != NULL) {
            memmove(b, buffer, ix);
            uint32_t msg = MSG_RX | ((uint32_t)b & 0x0fffffff); // SRAM_BASE is 0x20000000
            if (queue_is_full(&queue) || !queue_try_add(&queue, &msg)) {
                free(b);
            }
        }

        ix = 0;
    }
}

int main() {
    bi_decl(bi_program_description("Pico-Wiegand interface"));
    bi_decl(bi_program_version_string(VERSION));
    bi_decl(bi_1pin_with_name(ONBOARD_LED, "on-board LED"));

    // bi_decl(bi_1pin_with_name(READER_D0, "reader D0"));
    // bi_decl(bi_1pin_with_name(READER_D1, "reader D1"));
    // bi_decl(bi_1pin_with_name(READER_LED, "reader LED (out)"));

    // bi_decl(bi_1pin_with_name(WRITER_D0, "writer D0"));
    // bi_decl(bi_1pin_with_name(WRITER_D1, "writer D1"));
    // bi_decl(bi_1pin_with_name(WRITER_LED, "writer LED (in)"));

    stdio_init_all();
    setup_gpio();
    watchdog_enable(5000, true);

    // ... initialise RTC
    rtc_init();
    sleep_us(64);

    // ... initialise FIFO, UART and timers
    queue_init(&queue, sizeof(uint32_t), 64);
    setup_uart();
    alarm_pool_init_default();

    // ... initialise reader/emulator
    add_alarm_in_ms(250, startup, NULL, true);
    clear_screen();

    while (true) {
        uint32_t v;
        queue_remove_blocking(&queue, &v);

        if ((v & MSG) == MSG_SYSINIT) {
            sysinit();
        }

        if ((v & MSG) == MSG_SYSCHECK) {
            sys_ok();
        }

        if ((v & MSG) == MSG_WATCHDOG) {
            watchdog_update();
            blink(SYS_LED);
        }

        if ((v & MSG) == MSG_RX) {
            char *b = (char *)(SRAM_BASE | (v & 0x0fffffff));
            rx(b);
            free(b);
        }

        if ((v & MSG) == MSG_TX) {
            char *b = (char *)(SRAM_BASE | (v & 0x0fffffff));
            puts(b);
            free(b);
        }

        if ((v & MSG) == MSG_RXI) {
            on_card_rxi(v & 0x0fffffff);
        }

        if ((v & MSG) == MSG_CARD_READ) {
            on_card_read(v & 0x0fffffff);

            if (last_card.ok && ((mode == READER) || (mode == CONTROLLER))) {
                if (acl_allowed(last_card.facility_code, last_card.card_number)) {
                    last_card.granted = GRANTED;
                    led_blink(1);
                    door_unlock(5000);
                } else {
                    last_card.granted = DENIED;
                    led_blink(3);
                }
            }

            char s[64];
            cardf(&last_card, s, sizeof(s));
            puts(s);
        }

        if ((v & MSG) == MSG_LED) {
            led_event(v & 0x0fffffff);
        }

        if ((v & MSG) == MSG_RELAY) {
            relay_event(v & 0x0fffffff);
        }

        if ((v & MSG) == MSG_DOOR) {
            door_event(v & 0x0fffffff);
        }

        if ((v & MSG) == MSG_PUSHBUTTON) {
            pushbutton_event(v & 0x0fffffff);
        }

        if ((v & MSG) == MSG_DEBUG) {
            char s[64];
            snprintf(s, sizeof(s), "DEBUG %d", v & 0x0fffffff);
            puts(s);
        }
    }

    // ... cleanup

    queue_free(&queue);
}

void setup_gpio() {
    gpio_init(ONBOARD_LED);
    gpio_set_dir(ONBOARD_LED, GPIO_OUT);

    gpio_init(RELAY_NO);
    gpio_set_dir(RELAY_NO, GPIO_IN);
    gpio_pull_up(RELAY_NO);

    gpio_init(RELAY_NC);
    gpio_set_dir(RELAY_NC, GPIO_IN);
    gpio_pull_up(RELAY_NC);

    gpio_init(DOOR_SENSOR);
    gpio_set_dir(DOOR_SENSOR, GPIO_IN);
    gpio_pull_up(DOOR_SENSOR);

    gpio_init(PUSH_BUTTON);
    gpio_set_dir(PUSH_BUTTON, GPIO_IN);
    gpio_pull_up(PUSH_BUTTON);

    gpio_init(JUMPER_READ);
    gpio_set_dir(JUMPER_READ, GPIO_IN);
    gpio_pull_up(JUMPER_READ);

    gpio_init(JUMPER_WRITE);
    gpio_set_dir(JUMPER_WRITE, GPIO_IN);
    gpio_pull_up(JUMPER_WRITE);

    gpio_init(SD_DET);
    gpio_set_dir(SD_DET, GPIO_IN);
    gpio_pull_down(SD_DET);
}

void setup_uart() {
    uart_init(UART0, 2400);
    gpio_set_function(UART0_TX, GPIO_FUNC_UART);
    gpio_set_function(UART0_RX, GPIO_FUNC_UART);
    uart_set_baudrate(UART0, BAUD_RATE);
    uart_set_hw_flow(UART0, false, false);
    uart_set_format(UART0, DATA_BITS, STOP_BITS, PARITY);
    uart_set_fifo_enabled(UART0, false);
    irq_set_exclusive_handler(UART0_IRQ, on_uart0_rx);
    irq_set_enabled(UART0_IRQ, true);
    uart_set_irq_enables(UART0, true, false);
}

void sysinit() {
    static bool initialised = false;
    static repeating_timer_t watchdog_rt;
    static repeating_timer_t syscheck_rt;

    if (!initialised) {
        puts("                     SYS   STARTUP");

        if (!gpio_get(JUMPER_READ) && gpio_get(JUMPER_WRITE)) {
            mode = READER;
        } else if (gpio_get(JUMPER_READ) && !gpio_get(JUMPER_WRITE)) {
            mode = WRITER;
        } else {
            mode = UNKNOWN;
        }

        sdcard_initialise(mode);
        read_initialise(mode);
        write_initialise(mode);
        led_initialise(mode);
        buzzer_initialise(mode);
        TPIC_initialise(mode);

        if (!relay_initialise(mode)) {
            tx("failed to initialise relay monitor");
        }

        acl_initialise((uint32_t[]){}, 0);

        // ... setup sys stuff
        add_repeating_timer_ms(1250, watchdog, NULL, &watchdog_rt);
        add_repeating_timer_ms(5000, syscheck, NULL, &syscheck_rt);

        char dt[32];
        snprintf(dt, sizeof(dt), "%s %s", SYSDATE, SYSTIME);
        sys_settime(dt);

        rtc_get_datetime(&last_card.timestamp);
        sys_ok();
        set_scroll_area();

        // ... load ACL from SD card
        uint32_t cards[16];
        int N = 16;
        if (sdcard_read_acl(cards, &N) == 0) {
            acl_initialise(cards, N);
        }

        // ... 'k, done
        buzzer_beep(1);

        initialised = true;
    }
}

bool watchdog(repeating_timer_t *rt) {
    uint32_t v = MSG_WATCHDOG | 0x0000000;

    if (!queue_is_full(&queue)) {
        queue_try_add(&queue, &v);
    }

    return true;
}

bool syscheck(repeating_timer_t *rt) {
    uint32_t v = MSG_SYSCHECK | 0x0000000;

    if (!queue_is_full(&queue)) {
        queue_try_add(&queue, &v);
    }

    return true;
}

int64_t startup(alarm_id_t id, void *data) {
    uint32_t v = MSG_SYSINIT | 0x0000000;

    if (!queue_is_full(&queue)) {
        queue_try_add(&queue, &v);
    }

    return 0;
}

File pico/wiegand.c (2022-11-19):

#include "hardware/clocks.h"
#include "hardware/gpio.h"
#include "hardware/pio.h"
#include "pico/binary_info.h"
#include "pico/multicore.h"
#include "pico/stdlib.h"
#include "pico/util/queue.h"

#include <stdio.h>

#include "reader.h"
#include "wiegand.h"
#include <IN.pio.h>

#define VERSION "v0.0.0"

#define UART0 uart0
#define UART1 uart1
#define BAUD_RATE 115200
#define DATA_BITS 8
#define STOP_BITS 1
#define PARITY UART_PARITY_NONE

#define PIO_IN pio0
#define PIO_OUT pio1

void setup_gpio(void);
void setup_uart(void);
int count(uint32_t);

int64_t off(alarm_id_t, void *);
int64_t timeout(alarm_id_t, void *);
bool watchdog(repeating_timer_t *);
bool syscheck(repeating_timer_t *);

const uint GPIO_0 = 0;   // Pico 1
const uint GPIO_1 = 1;   // Pico 2
const uint GPIO_2 = 2;   // Pico 4
const uint GPIO_3 = 3;   // Pico 5
const uint GPIO_4 = 4;   // Pico 6
const uint GPIO_5 = 5;   // Pico 7
const uint GPIO_6 = 6;   // Pico 9
const uint GPIO_7 = 7;   // Pico 10
const uint GPIO_8 = 8;   // Pico 11
const uint GPIO_12 = 12; // Pico 16
const uint GPIO_13 = 13; // Pico 17
const uint GPIO_14 = 14; // Pico 19
const uint GPIO_15 = 15; // Pico 20
const uint GPIO_16 = 16; // Pico 21
const uint GPIO_17 = 17; // Pico 22
const uint GPIO_20 = 20; // Pico 26
const uint GPIO_21 = 21; // Pico 27
const uint GPIO_25 = 25; // Pico LED

const uint UART0_TX = GPIO_0;  // Pico 1
const uint UART0_RX = GPIO_1;  // Pico 2
const uint UART1_TX = GPIO_20; // Pico 26
const uint UART1_RX = GPIO_21; // Pico 27

const uint LED_PIN = GPIO_25;
const uint READER_LED = GPIO_15;
const uint YELLOW_LED = GPIO_14;
const uint ORANGE_LED = GPIO_13;
const uint BLUE_LED = GPIO_12;
const uint D0 = GPIO_16;
const uint D1 = GPIO_17;

const uint32_t MSG = 0xf0000000;
const uint32_t MSG_WATCHDOG = 0x00000000;
const uint32_t MSG_SYSCHECK = 0x10000000;
const uint32_t MSG_CARD_READ = 0x20000000;

queue_t queue;

// UART
void on_uart0_rx() {
    while (uart_is_readable(UART0)) {
        uint8_t ch = uart_getc(UART0);
        switch (ch) {
        case 'o':
        case 'O':
            gpio_put(READER_LED, 0);
            break;

        case 'x':
        case 'X':
            gpio_put(READER_LED, 1);
            break;
        }
    }
}

const LED SYS_LED = {
    .pin = LED_PIN,
    .timer = -1,
};

const LED TIMEOUT_LED = {
    .pin = YELLOW_LED,
    .timer = -1,
};

const LED BAD_LED = {
    .pin = ORANGE_LED,
    .timer = -1,
};

const LED GOOD_LED = {
    .pin = BLUE_LED,
    .timer = -1,
};

int main() {
    static repeating_timer_t watchdog_rt;
    static repeating_timer_t syscheck_rt;

    bi_decl(bi_program_description("Pico-Wiegand interface"));
    bi_decl(bi_program_version_string(VERSION));
    bi_decl(bi_1pin_with_name(LED_PIN, "on-board LED"));
    bi_decl(bi_1pin_with_name(READER_LED, "reader LED"));

    stdio_init_all();

    setup_gpio();
    setup_uart();

    // ... initialise FIFO
    queue_init(&queue, sizeof(uint32_t), 32);

    // ... initialise timers
    alarm_pool_init_default();

    // ... initialise reader
    reader_initialise();

    // ... start message
    { // 125MHz
        uint32_t hz = clock_get_hz(clk_sys);
        char s[64];
        snprintf(s, sizeof(s), "CLOCK %d", hz);
        puts(s);
    }

    add_repeating_timer_ms(2500, watchdog, NULL, &watchdog_rt);
    add_repeating_timer_ms(5000, syscheck, NULL, &syscheck_rt);

    uint32_t v;
    while (1) {
        queue_remove_blocking(&queue, &v);

        if ((v & MSG) == MSG_WATCHDOG) {
            blink((LED *)&SYS_LED);
        }

        if ((v & MSG) == MSG_SYSCHECK) {
            puts("SYS   OK");
        }

        if ((v & MSG) == MSG_CARD_READ) {
            int even = count(v & 0x03ffe000) % 2;
            int odd = count(v & 0x00001fff) % 2;
            uint32_t card = (v >> 1) & 0x00ffffff;
            uint32_t facility_code = (card >> 16) & 0x000000ff;
            uint32_t card_number = card & 0x0000ffff;

            char s[64];
            if (even != 0 || odd != 1) {
                blink((LED *)&BAD_LED);
                snprintf(s, sizeof(s), "CARD  %d%05d INVALID", facility_code, card_number);
            } else {
                blink((LED *)&GOOD_LED);
                snprintf(s, sizeof(s), "CARD  %d%05d OK", facility_code, card_number);
            }

            puts(s);
        }
    }

    // ... cleanup

    queue_free(&queue);
}

void setup_gpio() {
    gpio_init(LED_PIN);
    gpio_set_dir(LED_PIN, GPIO_OUT);

    gpio_init(READER_LED);
    gpio_set_dir(READER_LED, GPIO_OUT);
    gpio_pull_up(READER_LED);
    gpio_put(READER_LED, 1);

    gpio_init(YELLOW_LED);
    gpio_init(ORANGE_LED);
    gpio_init(BLUE_LED);

    gpio_set_dir(YELLOW_LED, GPIO_OUT);
    gpio_set_dir(ORANGE_LED, GPIO_OUT);
    gpio_set_dir(BLUE_LED, GPIO_OUT);

    gpio_put(YELLOW_LED, 0);
    gpio_put(ORANGE_LED, 0);
    gpio_put(BLUE_LED, 0);
}

void setup_uart() {
    uart_init(UART0, 2400);
    gpio_set_function(UART0_TX, GPIO_FUNC_UART);
    gpio_set_function(UART0_RX, GPIO_FUNC_UART);
    uart_set_baudrate(UART0, BAUD_RATE);
    uart_set_hw_flow(UART0, false, false);
    uart_set_format(UART0, DATA_BITS, STOP_BITS, PARITY);
    uart_set_fifo_enabled(UART0, false);
    irq_set_exclusive_handler(UART0_IRQ, on_uart0_rx);
    irq_set_enabled(UART0_IRQ, true);
    uart_set_irq_enables(UART0, true, false);
}

bool watchdog(repeating_timer_t *rt) {
    uint32_t v = MSG_WATCHDOG | 0x0000000;

    if (!queue_is_full(&queue)) {
        queue_try_add(&queue, &v);
    }

    return true;
}

bool syscheck(repeating_timer_t *rt) {
    uint32_t v = MSG_SYSCHECK | 0x0000000;

    if (!queue_is_full(&queue)) {
        queue_try_add(&queue, &v);
    }

    return true;
}

void blink(LED *led) {
    if (led->timer != -1) {
        cancel_alarm(led->timer);
    }

    gpio_put(led->pin, 1);

    led->timer = add_alarm_in_ms(250, off, (void *)led, true);
}

int64_t off(alarm_id_t id, void *data) {
    const LED *led = data;

    gpio_put(led->pin, 0);
    cancel_alarm(id);

    return 0;
}

int count(uint32_t v) {
    int N = 0;

    while (v != 0) {
        N++;
        v &= v - 1;
    }

    return N;
}

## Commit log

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2022-11-10 Fixing merge conflict
    [pico-wiegand.kicad_sch]
2022-11-10 Restored kicad file from backup
    [pico-wiegand.kicad_sch]
2022-11-11 Updated schematics with HID LED
    [pico-wiegand.kicad_sch, prototype.kicad_sch]
2022-11-13 PIO: replaced multicore + tight_loop_contents with PIO FIFO interrupt
    [wiegand.c]
2022-11-18 Replaced read delta timeout with timer/alarm
    [wiegand.c]
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2022-11-19 Moved watchdog and syscheck to repeating timers and reworked main loop to use blocking queue read
    [wiegand.c]
2022-11-23 Reworked set parity to use fast bit hack algorithm
    [wiegand.c]
2022-11-30 Moving PCB to branch
    [pico-wiegand.kicad_pcb, pico-wiegand.kicad_sch]
2022-11-30 Renamed KiCad 'prototype' to 'breadboard' because that is what it is
    [breadboard.kicad_pcb, breadboard.kicad_sch]
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2022-12-06 Fixed static CLI buffer initialisation
    [cli.c]
2022-12-20 Fixed CLI card/facility-code parsing
    [cli.c, wiegand.c]
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2022-12-27 Reworked emulator LED PIO to use 'pin' rather than 'gpio'
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2023-01-11 (interim commit) hunting down emulator freeze bug
    [cli.c, sys.c]
2023-01-12 Fixed lock-up after 2+ emulator writes (PIO FIFO blocking push in BLINK.PIO)
    [wiegand.c]
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2023-01-19 fritzing: added SD card breakout
    [uhppoted-wiegand-pico.fzz]
2023-01-20 fritzing: adding SD card breakout board
    [uhppoted-wiegand-pico.fzz]
2023-01-23 Added SD card lib
    [uhppoted-wiegand-pico.fzz]
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2023-01-27 Switched buzzer and red LED pins (because OCD)
    [wiegand.c]
2023-01-27 Updated Fritzing layout for swapped buzzer and red LED pin
    [uhppoted-wiegand-pico.fzz]
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2023-02-01 Updated breadboard with Phoenix connectors
    [uhppoted-wiegand-pico.fzz]
2023-02-02 Fritzing: fixed Wiegand D0/D1 routing
    [uhppoted-wiegand-pico.fzz]
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2023-02-03 Added relay inputs to Fritzing
    [uhppoted-wiegand-pico.fzz]
2023-02-06 Added pull-up and protection resistors to relay inputs
    [uhppoted-wiegand-pico.fzz]
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2023-02-07 Reworked relay NO/NC inputs to use LPFs
    [cli.c]
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2023-02-09 Adding relay module to Fritzing
    [uhppoted-wiegand-pico.fzz]
2023-02-10 Adding door and pushbutton contacts to Fritzing
    [uhppoted-wiegand-pico.fzz]
2023-02-13 Routing relays for pushbutton and door contact
    [uhppoted-wiegand-pico.fzz]
2023-02-14 Fritzing: reworking to use TPIC6595 I/O expander for relays
    [uhppoted-wiegand-pico-v0.fzz, uhppoted-wiegand-pico-v1.fzz]
2023-02-15 Fritzing: reworking layout for TPIC6592 I/O expander
    [uhppoted-wiegand-pico-v1.fzz]
2023-02-16 fritzing: shuffling v1 breadboard layout
    [uhppoted-wiegand-pico-v1.fzz]
2023-02-17 Tidied up Fritzing v.1 layout
    [uhppoted-wiegand-pico-v1.fzz]
2023-02-17 Routed Fritzing v.1 schematic
    [uhppoted-wiegand-pico-v1.fzz]
2023-02-20 Fritzing: tidied up v1 schematic
    [uhppoted-wiegand-pico-v1.fzz]
2023-02-21 Fritzing: corrected TPIC6B595 connections
    [uhppoted-wiegand-pico-v1.fzz]
2023-02-22 Replaced relay module with DPDT driven by TPIC6B595
    [uhppoted-wiegand-pico-v1.fzz]
2023-02-23 (interim commit) working reader without revised layout
    [uhppoted-wiegand-pico-v1.fzz]
2023-02-24 v1 breadboard: revised Wiegand reader/writer pin assignment
    [uhppoted-wiegand-pico-v1.fzz]
2023-02-24 v1 breadboard: revised relay NO/NC pin assignment
    [uhppoted-wiegand-pico-v1.fzz]
2023-02-27 Updated buzzer pin assignment for v1 breadboard
    [hwconfig.c]
2023-02-27 (interim commit) reassigned LED GPIO pins to TPIC SPI
    [uhppoted-wiegand-pico-v1.fzz]
2023-02-28 First pass at TPIC6B595 driver
    [uhppoted-wiegand-pico-v1.fzz]
2023-03-01 Moving LEDs to TPIC6B595
    [uhppoted-wiegand-pico-v1.fzz]
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2023-03-06 Added basic pushbutton read/write
    [uhppoted-wiegand-pico-v1.fzz]
2023-03-07 Restricted 'door unlock' to reader mode only
    [uhppoted-wiegand-pico-v1.fzz]
2023-03-07 Wrapped up reed relay contact emulation
    [uhppoted-wiegand-pico-v1.fzz]
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2023-03-10 Added derivative Fritzing layouts for emulator and controller
    [uhppoted-wiegand-pico-controller.fzz, uhppoted-wiegand-pico-emulator.fzz, uhppoted-wiegand-pico-v0.fzz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]
2023-03-10 fritzing: fixed mode jumper for controller
    [uhppoted-wiegand-pico-controller.fzz]
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2023-05-01 PicoW initial wireless skeleton (cf. https://github.com/uhppoted/uhppoted-wiegand/issues/1)
    [cli.c, controller.c, emulator.c]
2023-05-02 Externalised buzzer state to a struct and added check for initialised (blocks if not initialised)
    [buzzer.c]
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2023-05-04 Replaced blocking connect with async/poll and reenabled watchdog.
    [TPIC6B595.c, emulator.c]
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2023-05-09 Replaced buzzer PIO implementation with repeating timer to free up PIOs for PicoW
    [TPIC6B595.c, buzzer.c, hwconfig.c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]
2023-05-10 Replaced LED in PIO with a timer interrupt to free up PIO1 for the PicoW
    [emulator.c, hwconfig.c, led.c]
2023-05-11 Replaced reader LED blink PIO with timer to free up PIO resources for PicoW
    [buzzer.c, hwconfig.c, led.c]
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2023-05-11 Reworked emulator-w as a variant of emulator
    [cli.c, emulator.c]
2023-05-24 Replaced all UART tx(...) logging with logd_log
    [cli.c, controller.c, emulator.c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]
2023-05-29 Workaround for SD card detect interrupt conflict with cyw43 and USB enabled builds
    [cli.c, controller.c, sdcard.c]
2023-05-31 NTS: weird wifi disconnect resolved - cable modem instability
2023-05-31 reference+wifi: added missing MSG_LOG handler
    [emulator.c]
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2023-06-02 tcpd: replaced alarm with repeating timer
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2023-06-06 controller-picow-base: deferred SYSLED off to a queued msg to avoid lockup
    [controller.c, led.c]
2023-06-06 picow: debugging CYW43 and SYSLED issue
    [led.c]
2023-06-08 Initialised CYW43 SYSLED immediately after cyw43_arch_init (workaround for lock-acquire hang)
    [cli.c, controller.c, emulator.c]
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2023-06-12 Fixed logging in the base Pico versions
    [controller.c, emulator.c]
2023-08-14 Moved SD card read to ACL, preparatory to using onboard flash (cf. https://github.com/uhppoted/uhppoted-wiegand/issues/2)
    [cli.c, controller.c]
2023-08-15 Moved SDCARD writes to acl (cf. https://github.com/uhppoted/uhppoted-wiegand/issues/2)
    [cli.c]
2023-08-18 Reworked acl_load/save function signatures to return result code rather than message
    [cli.c, controller.c]
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2023-09-13 Keypad entry emulation using 4-bit burst mode Wiegand (cf. https://github.com/uhppoted/uhppoted-wiegand/issues/4)
    [cli.c]
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2023-09-15 Reading 4-bit Wiegand keypad codes (cf. https://github.com/uhppoted/uhppoted-wiegand/issues/4)
    [controller.c, emulator.c]
2023-09-20 Updated all emulator variants for keycodes (cf. https://github.com/uhppoted/uhppoted-wiegand/issues/4)
    [emulator.c]
2023-09-21 Added keycodes to reference implementation (cf. https://github.com/uhppoted/uhppoted-wiegand/issues/4)
    [cli.c]
2023-09-22 Adding keycode support to controllers (cf. https://github.com/uhppoted/uhppoted-wiegand/issues/4)
    [cli.c, controller.c, relays.c]
2023-09-26 Implemented master passcode for controller (cf. https://github.com/uhppoted/uhppoted-wiegand/issues/4)
    [cli.c, controller.c]
2023-09-28 Persisted passcodes to onboard flash (cf. https://github.com/uhppoted/uhppoted-wiegand/issues/4)
    [sdcard.c]
2023-10-02 Included passcodes in flash CRC (cf. https://github.com/uhppoted/uhppoted-wiegand/issues/4)
    [cli.c]
2023-10-04 Fixed write ACL to SD card logic
    [sdcard.c]
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2023-10-12 Added PIN code to CARD struct (cf. https://github.com/uhppoted/uhppoted-wiegand/issues/4)
    [cli.c, controller.c, emulator.c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]
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2023-10-16 controller: validates card+PIN (cf. https://github.com/uhppoted/uhppoted-wiegand/issues/4)
    [cli.c, controller.c]
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2023-10-19 Updated universal/picow/base for card + PIN (cf. https://github.com/uhppoted/uhppoted-wiegand/issues/4)
    [cli.c]
2023-10-20 Updated all picow variants for card+PIN (cf. https://github.com/uhppoted/uhppoted-wiegand/issues/4)
2023-10-23 Fixed the SD card read/write logic for card+PIN (cf. https://github.com/uhppoted/uhppoted-wiegand/issues/4)
    [sdcard.c]
2023-10-25 Replaced READER/WRITER with CONTROLLER/EMULATOR throughout and added keypad emulation information to README (cf. https://github.com/uhppoted/uhppoted-wiegand/issues/4)
    [cli.c, led.c, relays.c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]
2023-10-26 Keypad emulation wrap up (cf. https://github.com/uhppoted/uhppoted-wiegand/issues/4)
    [emulator.c]
2024-07-13 Fixed double keycode processing in emulator/picow
    [cli.c, emulator.c]
2024-09-06 Modified github workflow to use Pico SDK v1.1.5 (master branch broken)
2024-09-06 Modified github workflow to use Pico SDK 1.1.5 (master branch broken)
2024-09-06 Modified github workflow to use Pico SDK 1.1.5 (master branch seems broken)
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2024-09-06 Reverting to Pico SDK 1.5.1
2025-02-03 M5 stack: initial setup
    [uhppoted-wiegand-pico-base.fzz, uhppoted-wiegand-pico-controller.fzz, uhppoted-wiegand-pico-emulator.fzz]
2025-02-03 M5 stack: schematic - bus connectors
    [m5stack-wiegand-emulator.kicad_pcb, m5stack-wiegand-emulator.kicad_sch]
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2025-02-04 m5stack: yet more application notes
    [m5stack-wiegand-emulator.kicad_sch]
2025-02-05 M5: reworked RP2040-Tiny symbol
    [m5stack-wiegand-emulator.kicad_sch]
2025-02-05 M5: reworking WS2812 to use SN74HCT245
    [m5stack-wiegand-emulator.kicad_sch]
2025-02-05 M5: reworking LEDs to use SN74HCTx124 level translation
    [m5stack-wiegand-emulator.kicad_sch]
2025-02-06 M5Stack: reworked WS2821 to use SN74HCT1G125
    [m5stack-wiegand-emulator.kicad_sch]
2025-02-07 M5: ISOW7842 digital isolator and SN74LVC2G12 line driver
    [m5stack-wiegand-emulator.kicad_sch]
2025-02-10 M5: pullup for WS2812 DIN
    [m5stack-wiegand-emulator.kicad_sch]
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2025-02-10 M5: MOVs for line driver
    [m5stack-wiegand-emulator.kicad_sch]
2025-02-11 M5: reworked to use ISO7841 and INC to drive line driver OE
    [m5stack-wiegand-emulator.kicad_sch]
2025-02-13 M5: 12V power converter
    [m5stack-wiegand-emulator.kicad_sch]
2025-02-13 M5: replaced TPS62713 regulator with TPS629206 (SOT-583)
    [m5stack-wiegand-emulator.kicad_sch]
2025-02-14 M5: replaced MOVs with TVS diodes
    [m5stack-wiegand-emulator.kicad_sch]
2025-02-17 M5: PCB outline and mounting holes
    [Base26_main.stl, Module-Type-A.PcbDoc, Module-Type-A.dxf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]
2025-02-18 M5: added BAT54S input protection to LED
    [m5stack-wiegand-emulator.kicad_sch]
2025-02-18 M5: corrected cutout offset on PCB
    [m5stack-wiegand-emulator.kicad_pcb]
2025-02-18 M5: placed J1/J2 connectors
    [m5stack-wiegand-emulator.kicad_pcb, m5stack-wiegand-emulator.kicad_sch]
2025-02-19 M5: adding missing footprints
    [m5stack-wiegand-emulator.kicad_pcb, m5stack-wiegand-emulator.kicad_sch]
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2025-02-20 M5: changed L1 footprint to Vishay/1210
    [m5stack-wiegand-emulator.kicad_pcb, m5stack-wiegand-emulator.kicad_sch]
2025-02-21 M5: placed all footprints
    [m5stack-wiegand-emulator.kicad_pcb, m5stack-wiegand-emulator.kicad_sch]
2025-02-24 M5: replaced SMD TVS diodes with THT (for hand-soldering)
    [m5stack-wiegand-emulator.kicad_pcb, m5stack-wiegand-emulator.kicad_sch]
2025-02-24 M5: replaced discrete'ish switchmode with module
    [m5stack-wiegand-emulator.kicad_pcb, m5stack-wiegand-emulator.kicad_sch]
2025-02-25 M5: added optional resistors to set drive current for DI/DO
    [m5stack-wiegand-emulator.kicad_pcb, m5stack-wiegand-emulator.kicad_sch]
2025-02-25 M5: added solder jumpers for TC/RX
    [m5stack-wiegand-emulator.kicad_pcb, m5stack-wiegand-emulator.kicad_sch]
2025-02-25 M5: replaced WS2812 driver with output from ISOW7843
    [m5stack-wiegand-emulator.kicad_pcb, m5stack-wiegand-emulator.kicad_sch]
2025-02-25 M5: replaced THT TranzOrbs with SMD
    [m5stack-wiegand-emulator.kicad_pcb, m5stack-wiegand-emulator.kicad_sch]
2025-02-26 M5: reworked PCB footprints for overlap
    [m5stack-wiegand-emulator.kicad_pcb, m5stack-wiegand-emulator.kicad_sch]
2025-02-27 M5: added fiducial marks and logo/revision
    [m5stack-wiegand-emulator.kicad_pcb, m5stack-wiegand-emulator.kicad_sch]
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2025-03-04 Relocated J3 connector and rerouted
    [m5stack-wiegand-emulator.kicad_pcb, m5stack-wiegand-emulator.kicad_sch]
2025-03-05 M5: fixed (most) ERC violations
    [m5stack-wiegand-emulator.kicad_pcb, m5stack-wiegand-emulator.kicad_sch]
2025-03-05 M5: routed DI/DO signals
    [m5stack-wiegand-emulator.kicad_pcb, m5stack-wiegand-emulator.kicad_sch]
2025-03-05 M5: moved DI/DO to GP28/29"
    [m5stack-wiegand-emulator.kicad_pcb, m5stack-wiegand-emulator.kicad_sch]
2025-03-06 M5: routing LED IN signal
    [m5stack-wiegand-emulator.kicad_pcb, m5stack-wiegand-emulator.kicad_sch]
2025-03-10 M5: rotated U1 and U2 and rerouted
    [m5stack-wiegand-emulator.kicad_pcb, m5stack-wiegand-emulator.kicad_sch]
2025-03-11 M5: recalculated LED input resistance
    [m5stack-wiegand-emulator.kicad_pcb, m5stack-wiegand-emulator.kicad_sch]
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2025-03-17 M5: replaced J1+J2 with single THT connector
    [m5stack-wiegand-emulator.kicad_pcb, m5stack-wiegand-emulator.kicad_sch]
2025-03-18 M5: corrected ISOW7841 3D model
    [m5stack-wiegand-emulator.kicad_pcb, m5stack-wiegand-emulator.kicad_sch]
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2025-03-20 M5: reworked M5 bus connector footprint
    [m5stack-wiegand-emulator.kicad_pcb, m5stack-wiegand-emulator.kicad_sch]
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2025-04-16 M5: fixed 15 pin female connector locator hole footprint
    [m5stack-wiegand-emulator.kicad_pcb, m5stack-wiegand-emulator.kicad_sch]
2025-04-16 M5: removed solder jumpers and test points from BOM
    [m5stack-wiegand-emulator.kicad_sch]
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2025-06-26 M5: added ISOW7841 RC filter to Rev.0 errata list
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2025-07-21 M5: returned ok/error on UART command
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
